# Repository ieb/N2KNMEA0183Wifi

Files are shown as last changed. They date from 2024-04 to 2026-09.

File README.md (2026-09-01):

# N2K / NMEA0183 WiFi + BLE bridge

ESP32-C3 firmware that bridges an NMEA2000 (CAN) bus to WiFi and Bluetooth LE
clients. Parses a working subset of N2K PGNs, emits NMEA0183 and SeaSmart over
TCP/UDP/HTTP streams, serves a local web UI and admin, and publishes a
compact binary boat-state feed over BLE GATT for mobile PWAs.

Also bridges a JBD / JDB BMS over TTL/UART, exposing register data both as
custom PGNs on the N2K bus and as a dedicated BLE battery characteristic.

## Features

* NMEA2000 CAN node — parse + emit, built on top of the NMEA2000 library.
* NMEA0183 generation from N2K PGNs (see `lib/N2KHandler/NMEA0183N2KMessages.h`).
* TCP server on port 10110, UDP broadcast, and long-lived chunked HTTP streams
  (`/api/nmea0183`, `/api/seasmart`) with per-client PGN filtering.
* SeaSmart (PCDIN) passthrough with filter negotiation.
* BLE GATT server (`BoatWatchBLE`) — see `docs/ble-transport.md`:
  * `0xAA00` service — autopilot state, command channel, battery.
  * `0xFF00` service — navigation state (lat/lon, COG/SOG, heading, wind,
    depth, STW, log) and engine state (RPM, temps, volts, pressures, hours,
    status bits).
  * PIN-based auth with per-connection and global brute-force lockouts.
  * Fields revert to "not available" sentinels when their source PGN stops
    arriving (≤15 s for nav and slow-cadence engine fields; 5 s for
    engine-running-only fields), so clients don't see stale values.
* JBD BMS bridge over UART — cell voltages, pack V/I/SoC, temps, FET status,
  errors.
* Engine freeze-frame logging to flash (`lib/freezeframe`).
* Performance calculations (polar VMG, target boat speed, target wind angle,
  leeway — see `lib/performance`).
* Logbook to SPIFFS (`lib/logbook`).
* HTTP admin interface (config upload, FS operations, reboot, status).
* WiFi station or AP mode, mDNS.

## UIs

The UIs live in their own repos and talk to the firmware over HTTP streams
or BLE:

* [N2KBMSFwUi](https://github.com/ieb/N2KBMSFwUi) — read-only SPIFFS-hosted UI
  for mobile browsers.
* [N2KUi](https://github.com/ieb/N2KUi) — installable PWA with admin.
* [N2KLifePo4](https://github.com/ieb/N2KLifePo4) — installable PWA for the
  LiFePO4 BMS (BLE).
* [NMEA2000_Booklet](https://github.com/ieb/NMEA2000_Booklet) — Kindle 4
  booklet for use on deck in sunlight.

## Hardware

Current target is an ESP32-C3 on a custom PCB (see `pcb/`). Brownout
threshold is lowered from the 3.1 V default to 2.8 V to ride out BLE radio
bring-up transients. CAN transceiver, isolated UART to the BMS, LED, and
connectors are documented in the schematic.

<div>
ESP32-C3 board
</div>

## HTTP API

All paths marked "admin only" require HTTP basic auth against credentials in
`config.txt`.

| Method | Path | Purpose |
| --- | ---- | --- |
| GET  | `/**` | Static file from SPIFFS (UI bundle). |
| GET  | `/api/store` | Current store snapshot, CSV. |
| GET  | `/api/devices` | Devices seen on the N2K bus, text. |
| GET  | `/api/nmea0183` | Chunked NMEA0183 stream. |
| GET  | `/api/seasmart` | Chunked SeaSmart stream; `?pgns=...` filters. |
| GET  | `/api/status.json` | Filesystem + heap status. *admin* |
| GET  | `/api/fs.json` | Filesystem listing. *admin* |
| POST | `/api/fs.json` | `op=delete` or `op=upload` (multipart). *admin* |
| GET  | `/config.txt` | Current configuration file. *admin* |
| POST | `/api/reboot.json` | Reboot. *admin* |

Simulators for the HTTP/TCP/BMS side live under `simulator/`.

## TCP / UDP (port 10110)

Emits NMEA0183 sentences by default. A client can switch its session to
SeaSmart by sending a PGN filter request — once switched, the stream stays
in SeaSmart mode for that client. Some noisy PGNs (e.g. Raymarine pilot
updates) are filtered by default to protect bandwidth.

    $PCDCM,1,7,127489,127505,127488,128259,129026,130312,128267*77

UDP is used for broadcast to LAN clients. Note that ChromeOS blocks UDP
broadcast to Android apps running in containers, so the TCP and HTTP stream
paths exist as a workaround.

## BLE

See `docs/ble-transport.md` for the binary frame layouts, magic bytes,
scaling factors, and notification cadence. Characteristics notify at ≤2 Hz
when data changes, and fall back to a 1 Hz keep-alive carrying the latest
values (or NA sentinels if the source PGN has gone stale).

Authentication is a 4-digit PIN (`ble.pin` in `config.txt`). Brute force is
bounded by a per-connection lockout (30 s after 5 failures, disconnect after
10) and a global lockout (5 min after 20 cumulative failures across all
connections). Unauthenticated clients are disconnected after 30 s.

## SeaSmart format reference

SeaSmart/PCDIN sentences published on the NMEA0183 streams:

    $PCDIN,01F119,00000000,0F,2AAF00D1067414FF*59
                                               ^^ checksum
                              ^^^^^^^^^^^^^^^^ data (whole message)
                           ^^ source
                  ^^^^^^^^ hex time
           ^^^^^^ PGN
    ^^^^^^ NMEA0183 id

Hex time decoded as `((parseInt(value,32)/1024)+1262304000)*1000` giving ms
since 1970. Reference: [SeaSmart protocol PDF](http://www.seasmart.net/pdf/SeaSmart_HTTP_Protocol_RevG_043012.pdf).

## Usage

On boot the firmware reads `data/config.txt` from SPIFFS and either joins
the configured WiFi network (station mode) or starts its own AP. Find the
resulting IP, then:

* `http://<ip>/`          — data / status view.
* `http://<ip>/admin.html` — admin view (upload config, reboot).

A serial monitor on the ESP32 gives lower-level diagnostics; press `h<CR>`
for a help screen. The running git SHA is printed with `h`.

## Developing

Project uses PlatformIO. Default environment is `esp32-c3`.

    pio run                                  # build firmware
    pio run -t upload                        # flash firmware
    pio run --target buildfs -e esp32-c3     # build SPIFFS image
    pio run --target uploadfs -e esp32-c3    # flash SPIFFS image
    pio device monitor                       # serial console

The SPIFFS image is populated from `data/`. To repopulate it from the
current UI source, clone the relevant UI repo (for the read-only UI that's
[N2KBMSFwUi](https://github.com/ieb/N2KBMSFwUi)) and run its build script.
Simulators under `simulator/` are Node-based and useful for exercising the
HTTP/TCP/BMS paths without hardware.

## Known limitations / history

* WebSockets were removed — the ESP async WebSocket library crashes when
  more than one client connects and the upstream bug is unfixed. Chunked
  HTTP streams replaced them and are stable under load.
* Earlier PCB revisions carried a BME280, ADS1115, TFT display, touch
  sensors, and an OLED. These are all archived — sensing moved to external
  CAN-based sensors (see CanPressure) and display moved to apps. The
  archived code lives under `lib/archive/`.
* An earlier instability was traced to blocking TCP writes hanging the main
  loop; fixed by moving to an async TCP server. CAN bus loaded to 100 % is
  handled without drops.

## Layout

    src/                 firmware entry point
    lib/
      N2KHandler/        PGN parsing, NMEA0183 emitters, freeze-frame hooks
      bluetooth/         BoatWatch BLE server, engine/nav encoders
      network/           HTTP, TCP, UDP, mDNS, wifi bring-up
      jdbbms/            JBD/JDB BMS UART driver
      performance/       polar-based performance calculations
      logbook/           SPIFFS logbook writer
      freezeframe/       engine event freeze-frame recorder
      config/            config.txt loader
    docs/ble-transport.md   BLE GATT + binary framing spec
    simulator/           Node-based HTTP/TCP/BMS simulators
    pcb/                 board design files
    ui/                  scratch / local UI assets (main UIs are in separate repos)

# BUGS/TODO

* [x] Chromebook and Phone continue to show connection instability. Probably fixed with a 500ppm SCA setting.

## Chromebook and Phone continue to show connection instability. 

Could be the shared WiFi/BLE chips in both devices, but could also be the ESP32 having a 500ppm sleep clock accuracy (SCA). Default with NimBLE seems to be 60ppm. I see 520 connection closed reasons in the ESP32 logs, https://github.com/apache/mynewt-nimble/issues/1777 indicates SCA could be the cause.

Testing over 48h is not conclusive since the WiFi environment is not as challenging with weak signals causing the OS interfer with BLE while prioritising Wifi. However, there seem to be fewer disconnects due to 520, and on that basis I am keeping the 500ppm setting for SCA in this commit.

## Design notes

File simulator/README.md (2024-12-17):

# Various simulators

Simulators used to develop the frimware and clients to the firmware.

Simulate JBD BMS on a serial port at 9600 baud so the firmware can experience a BMS serial port.

node bmssim.js 

Simulate the embedded http api server for seasmart and nmea0183 streams

node index.js

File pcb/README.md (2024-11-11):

# PCBs

There are 2 variant, one for an ESP32 WROOM board and one for ESP32-C3 boards. 2 PCBs for the later one using the 18n pin waveshare module and the other using a generic 16 pin module from ebay.

The BMS serial is isolated with a pair of 6N137s as 0v of the BMS will likely not be 0V of the Canbus due to current flowing from the battery pack.  The device is powered from the canbus which is driven through a TJ1050.  The preferred board is one of the ESP32-C3 boards which are more compact and better designed.

# Gcode generation.

For each board, in KiCad
* generate gerbers for front, back and edge.
* generate 1 drill file with all drills.
* Turn of X2 gerber commands as this creates codes that pcb2gcode wont understand.
* decide on where the mirror line will be, default is X=60, which uses a lot of bed space, sometimes best to use a midpoint on X.
* decide where the alignment holes will be, default is +-10 from the mirror, any y10,80. 4 in total.
* run

        ./createGCode.sh <boardname> <mirrorX> <alignOffsetX>  <alignLowerY> <alignUpperY>
        where:
            boardname is the name of the board
            mirrorX is the X of the mirror line, default 60.
            alignOffsetX is the X distance of alignment holes from the mirror line, default = 10
            alignLowerY is the lower Y position default = 10
            alignUpperY is the upper Y position default = 80

* check the output at https://ncviewer.com/

# Milling

NM grbl 0.9 doesnt process M6 or G81 so both are to be disabled during gcode generation.

* mill the fron side,
* drill alignment
* flip and align
* mill backside
* flip and align
* drill from the frontside

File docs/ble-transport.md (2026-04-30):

# BLE Transport Protocol

The firmware exposes two BLE GATT services: the **BoatWatch Service** for autopilot control and battery monitoring, and the **NMEABridge Nav Service** for navigation data. Up to 3 BLE clients may connect simultaneously.

## Connection

1. Scan for service UUID `0000AA00` (BoatWatch) or `0000FF00` (Nav)
2. Connect GATT
3. Request MTU (64 minimum, 512 recommended)
4. Discover services
5. Enable notifications via CCC descriptor write (UUID `00002902`)
6. Auto-reconnect on disconnect after 3 seconds

Byte order is **little-endian** for all multi-byte values throughout both services.

---

## BoatWatch Service (0xAA00)

Intended mostly for use by wearOS Apps.

| UUID | Characteristic | Properties | Direction |
|---|---|---|---|
| `0000AA00-0000-1000-8000-00805f9b34fb` | Service | -- | -- |
| `0000AA01-0000-1000-8000-00805f9b34fb` | Autopilot State | NOTIFY, READ | Firmware -> Client |
| `0000AA02-0000-1000-8000-00805f9b34fb` | Command | WRITE | Client -> Firmware |
| `0000AA03-0000-1000-8000-00805f9b34fb` | Battery State | NOTIFY, READ | Firmware -> Client |

### Authentication

Autopilot state and battery notifications require authentication. After subscribing to notifications, write an auth command to `0xAA02`:

| Offset | Size | Type | Field | Value |
|---|---|---|---|---|
| 0 | 1 | U8 | magic | `0xAA` |
| 1 | 1 | U8 | cmd | `0xF0` (AUTH) |
| 2 | 4 | char[4] | PIN | ASCII digits, e.g. `"0000"` |

The firmware responds with an auth result notification on both `0xAA01` and `0xAA03`:

| Offset | Size | Type | Field | Value |
|---|---|---|---|---|
| 0 | 1 | U8 | magic | `0xAF` |
| 1 | 1 | U8 | result | `0x01` = accepted, `0x00` = denied |

### Autopilot State (0xAA01)

Magic byte: `0xAA`. Payload: 10 bytes. Update rate: every 5 seconds or on change.

| Offset | Size | Type | Field | Scale/Values |
|---|---|---|---|---|
| 0 | 1 | U8 | magic | `0xAA` |
| 1 | 1 | U8 | mode | 0=STANDBY, 1=COMPASS, 2=WIND_AWA, 3=WIND_TWA |
| 2 | 2 | U16 | current_heading | 0.01 deg (0-36000) |
| 4 | 2 | U16 | target_heading | 0.01 deg (0-36000) |
| 6 | 2 | S16 | target_wind | 0.01 deg (-18000 to +18000) |
| 8 | 2 | U16 | reserved | `0x0000` |

### Commands (0xAA02)

Magic byte: `0xAA`. All commands require prior authentication.

**Autopilot Mode commands (2 bytes, no payload):**

| Cmd | Name |
|-----|---|
| `0x01` | STANDBY |
| `0x02` | COMPASS (heading hold) |
| `0x03` | WIND_AWA (apparent wind) |
| `0x04` | WIND_TWA (true wind) |

**Autopilot Set commands (4 bytes, U16 or S16 payload):**

| Cmd | Name | Payload | Unit |
|-----|---|---|---|
| `0x10` | SET_HEADING | U16 | 0.01 deg (0-36000) |
| `0x11` | SET_WIND | S16 | 0.01 deg |

**Autopilot Adjust commands (4 bytes, S16 payload):**

| Cmd | Name | Payload | Unit |
|-----|---|---|---|
| `0x20` | ADJUST_HEADING | S16 | 0.01 deg delta |
| `0x21` | ADJUST_WIND | S16 | 0.01 deg delta |

**Wifi Adjust commands (2 bytes, No payload):**

| Cmd | Name | Payload | Unit |
|-----|---|---|---|
| `0x40` | ENABLE_WIFI | None | NA |
| `0x41` | DISABLE_WIFI | None | NA |

### Battery State (0xAA03)

Magic byte: `0xBB`. Payload: variable (typically 31 bytes for 4 cells, 3 NTC). Update rate: every 5 seconds or on change.

| Offset | Size | Type | Field | Scale |
|---|---|---|---|---|
| 0 | 1 | U8 | magic | `0xBB` |
| 1 | 2 | U16 | pack_voltage | 0.01 V |
| 3 | 2 | S16 | current | 0.01 A |
| 5 | 2 | U16 | remaining_ah | 0.01 Ah |
| 7 | 2 | U16 | full_ah | 0.01 Ah |
| 9 | 1 | U8 | soc | 1% (0-100) |
| 10 | 2 | U16 | cycles | 1 |
| 12 | 2 | U16 | errors | bitmap (16 protection flags) |
| 14 | 1 | U8 | fet_status | bit0=charge, bit1=discharge |
| 15 | 1 | U8 | n_cells | count |
| 16 | 2*N | U16[] | cell_voltages | 0.001 V each |
| 16+2N | 1 | U8 | n_ntc | count |
| 17+2N | 2*M | U16[] | ntc_temps | 0.1 K (convert: val*0.1 - 273.15 = C) |

---

## NMEABridge Nav Service (0xFF00)

| UUID | Characteristic | Properties | Direction |
|---|---|---|---|
| `0000FF00-0000-1000-8000-00805f9b34fb` | Service | -- | -- |
| `0000FF01-0000-1000-8000-00805f9b34fb` | Navigation State | NOTIFY, READ | Firmware -> Client |
| `0000FF02-0000-1000-8000-00805f9b34fb` | Engine State | NOTIFY, READ | Firmware -> Client |
| `0000FF03-0000-1000-8000-00805f9b34fb` | System | Write |  Client -> Firmware |

Authentication required. Only Authenticated clients receive navigation and engine data.

### Navigation State (0xFF01)

Magic byte: `0xCC`. Payload: 29 bytes. Update rate: 1 Hz.

| Offset | Size | Type | Field | Scale | Range |
|---|---|---|---|---|---|
| 0 | 1 | U8 | magic | `0xCC` | identifier |
| 1 | 4 | S32 | latitude | 1e-7 deg | +/-90 deg |
| 5 | 4 | S32 | longitude | 1e-7 deg | +/-180 deg |
| 9 | 2 | U16 | cog | 0.0001 rad | 0-6.2832 |
| 11 | 2 | U16 | sog | 0.01 m/s | 0-655.34 |
| 13 | 2 | S16 | variation | 0.0001 rad | +/-3.1416 |
| 15 | 2 | U16 | heading | 0.0001 rad | 0-6.2832 |
| 17 | 2 | U16 | depth | 0.01 m | 0-655.34 |
| 19 | 2 | U16 | awa | 0.0001 rad | 0-6.2832 |
| 21 | 2 | U16 | aws | 0.01 m/s | 0-655.34 |
| 23 | 2 | U16 | stw | 0.01 m/s | 0-655.34 |
| 25 | 4 | U32 | log | 1 m | 0-4,294,967,294 |

**Data Not Available sentinels (NMEA 2000 convention):**

| Type | Sentinel |
|---|---|
| U16 | `0xFFFF` |
| S16 | `0x7FFF` |
| U32 | `0xFFFFFFFF` |
| S32 | `0x7FFFFFFF` |

### Example payload

```
hex: CC 60 13 D8 1D 40 6A 56 FA 5C 3D 01 01 57 00 5C 3D E2 04 AE 1E 20 03 F0 00 98 3A 00 00
```

Decodes to: 50.0700 N, 009.5000 W, COG 90.0 deg, SOG 2.57 m/s, VAR 0.5 deg E, HDG 90.0 deg, DEPTH 12.50 m, AWA 45.0 deg, AWS 8.00 m/s, STW 2.40 m/s, LOG 15000 m

### Engine State (0xFF02)

Magic byte: `0xDD`. Payload: 27 bytes. Update rate: 1 Hz max, notify on change. Single engine (instance 0).

The engine is not always running. When 127488 / 127489 stop arriving, the firmware applies a 5 s staleness timeout and reports the "not available" sentinel for RPM, coolant, alternator V/T, oil pressure and status bits. Fuel level, engine-room temperature and engine battery voltage continue to update regardless.

| Offset | Size | Type | Field | Scale | Range |
|---|---|---|---|---|---|
| 0  | 1 | U8  | magic | `0xDD` | identifier |
| 1  | 2 | U16 | rpm | 0.25 rpm/bit | 0-16383.75 rpm |
| 3  | 4 | U32 | engine_hours | 1 s/bit | cumulative, EEPROM-backed |
| 7  | 2 | U16 | coolant_temp | 0.01 K | convert: `val*0.01 - 273.15` = degC |
| 9  | 2 | U16 | alternator_temp | 0.01 K | convert: `val*0.01 - 273.15` = degC (see Non-Standard Mappings) |
| 11 | 2 | U16 | alternator_volts | 0.01 V | 0-655.34 V |
| 13 | 2 | U16 | oil_pressure | 100 Pa/bit | 0-6553400 Pa (1 hPa per count) |
| 15 | 2 | U16 | exhaust_temp | 0.01 K | PGN 130312/130316 source 14 |
| 17 | 2 | U16 | engine_room_temp | 0.01 K | PGN 130312/130316 source 3 |
| 19 | 2 | U16 | engine_batt_volts  | 0.01 V | cranking battery, PGN 127508 instance 0 |
| 21 | 2 | U16 | fuel_level | 0.004 %/bit  | 0-25000 = 0-100 % |
| 23 | 2 | U16 | status1 | bitmap | see Status Bits |
| 25 | 2 | U16 | status2 | bitmap | see Status Bits |

**Data Not Available sentinels** (same convention as Navigation State): `U16 = 0xFFFF`, `U32 = 0xFFFFFFFF`.

#### Status Bits

`status1` - PGN 127489 Discrete Status 1:

| Bit | Mask | Name | Trigger |
|-----|---|---|---|
| 0  | `0x0001` | CHECK_ENGINE | latched on any fault |
| 1  | `0x0002` | OVER_TEMPERATURE | coolant > 97 degC for 15 s |
| 2  | `0x0004` | LOW_OIL_PRESSURE | oil < ~68.9 kPa for 5 s (only while > 800 rpm) |
| 5  | `0x0020` | LOW_SYSTEM_VOLTAGE | battery < 11.8 V for 5 s |
| 7  | `0x0080` | WATER_FLOW | exhaust > 80 degC |
| 9  | `0x0200` | CHARGE_INDICATOR | alternator < 12.2 V for 5 s |
| 15 | `0x8000` | EMERGENCY_STOP | latched |

`status2` - PGN 127489 Discrete Status 2:

| Bit | Mask | Name | Trigger |
|-----|---|---|---|
| 3 | `0x0008` | MAINTENANCE_NEEDED | scheduled service due |
| 4 | `0x0010` | ENGINE_COMM_ERROR | sensor failure detected |
| 7 | `0x0080` | ENGINE_SHUTTING_DOWN  | RPM dropped below 500 with alarms latched |

All other bits are reserved and should be masked off by clients.

#### Non-Standard Mappings

The upstream N2KEngine firmware (https://github.com/ieb/N2KEngine) remaps several PGN fields to carry measurements that have no standard slot. Consumers that read the source PGNs directly must be aware of these remappings; this characteristic presents the decoded values in their logical positions.

1. **`alternator_temp` originates from the PGN 127489 engine-oil-temperature field.** The engine has no oil temperature sensor. The firmware comment ("alternator temperature as engineOil temperature, more important with LiFePO4") documents the substitution. True oil temperature is never emitted.
2. **PGN 127508 instance 2 is a synthetic "battery"** whose Battery Voltage = alternator output and Battery Temperature = alternator NTC. It is not a real battery. `alternator_volts` and `alternator_temp` in this characteristic are sourced from PGN 127489, not from instance 2; clients should ignore PGN 127508 instance 2 entirely.
3. **N2KEngine may emit the engine temperature triplet on legacy PGN 130312 or on PGN 130316.** The bridge accepts either PGN for source 14 (exhaust) and source 3 (engine room) and normalizes them into this characteristic.
4. **Firmware-proprietary temperature sources 30 and 31+** are not surfaced here. Source 30 duplicates the alternator NTC, while sources 31+N expose OneWire DS18B20 probes of variable count.

Exhaust temperature (source 14) and engine-room temperature (source 3) are standard NMEA 2000 temperature sources.

#### Fields deliberately excluded

The N2KEngine firmware never populates fuel rate, coolant pressure, fuel pressure, boost pressure, engine load, engine torque or tilt/trim, so they are omitted here.

### Example payload

```
hex: DD 20 1C F0 D3 1D 00 E7 8B FF 87 8C 05 AC 0D B3 E7 4B 73 EC 04 3E 49 00 00 00 00
```

Decodes to: RPM 1800, engine_hours 543 h (1,954,800 s), coolant 85.0 degC, alternator 75.0 degC / 14.20 V, oil pressure 350 kPa, exhaust 320.0 degC, engine room 22.0 degC, engine battery 12.60 V, fuel 75.0 %, no alarms.

---

#### Data Sources

| Field | NMEA 2000 PGN | Notes |
|---|---|---|
| Latitude, Longitude | 129025, 129029 | GNSS position |
| COG, SOG | 129026 | Course/speed over ground |
| Variation | 127258, 127250 | Magnetic variation |
| Heading | 127250 | Magnetic heading |
| Depth | 128267 | Depth below transducer |
| AWA, AWS | 130306 | Apparent wind |
| STW | 128259 | Speed through water |
| Log | 128275 | Cumulative distance |
| Autopilot | 65379, 65359, 65360, 65345 | Raymarine proprietary |
| Battery | JDB BMS via serial | Registers 03/04 |
| Engine RPM | 127488 | Rapid engine, 500 ms |
| Engine hours, coolant, alternator V, alternator T, oil pressure, status | 127489 | Dynamic engine, 1 s; alternator T carried in oil-temp field (remap) |
| Exhaust temp | 130312/130316 src 14 | Legacy/extended temperature |
| Engine room temp | 130312/130316 src 3  | Legacy/extended temperature |
| Engine battery volts | 127508 instance 0 | Cranking battery |
| Fuel level | 127505 instance 0 | Diesel, 60 L capacity |

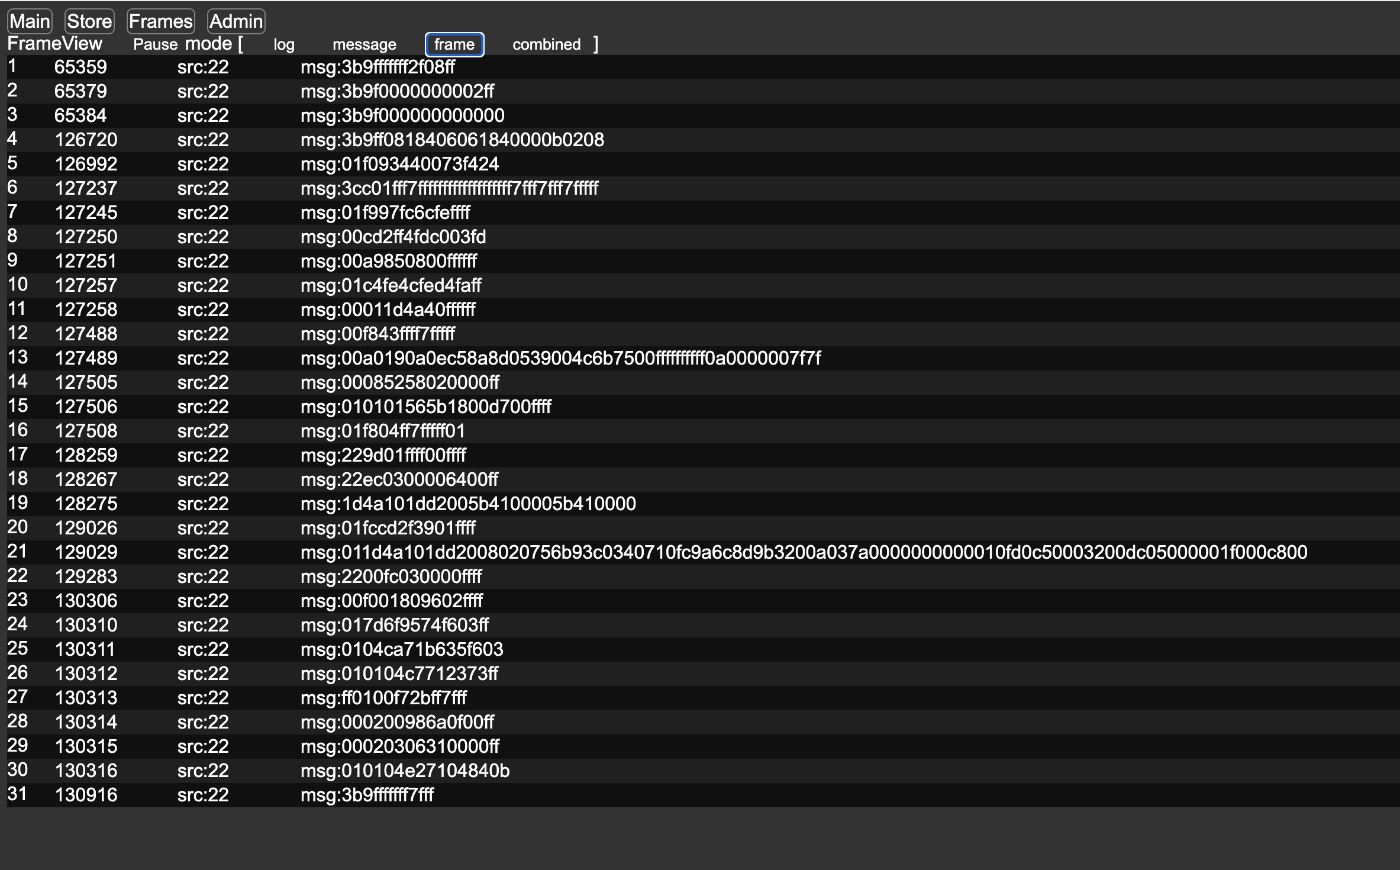
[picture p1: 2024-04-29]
screenshots/frameview.png

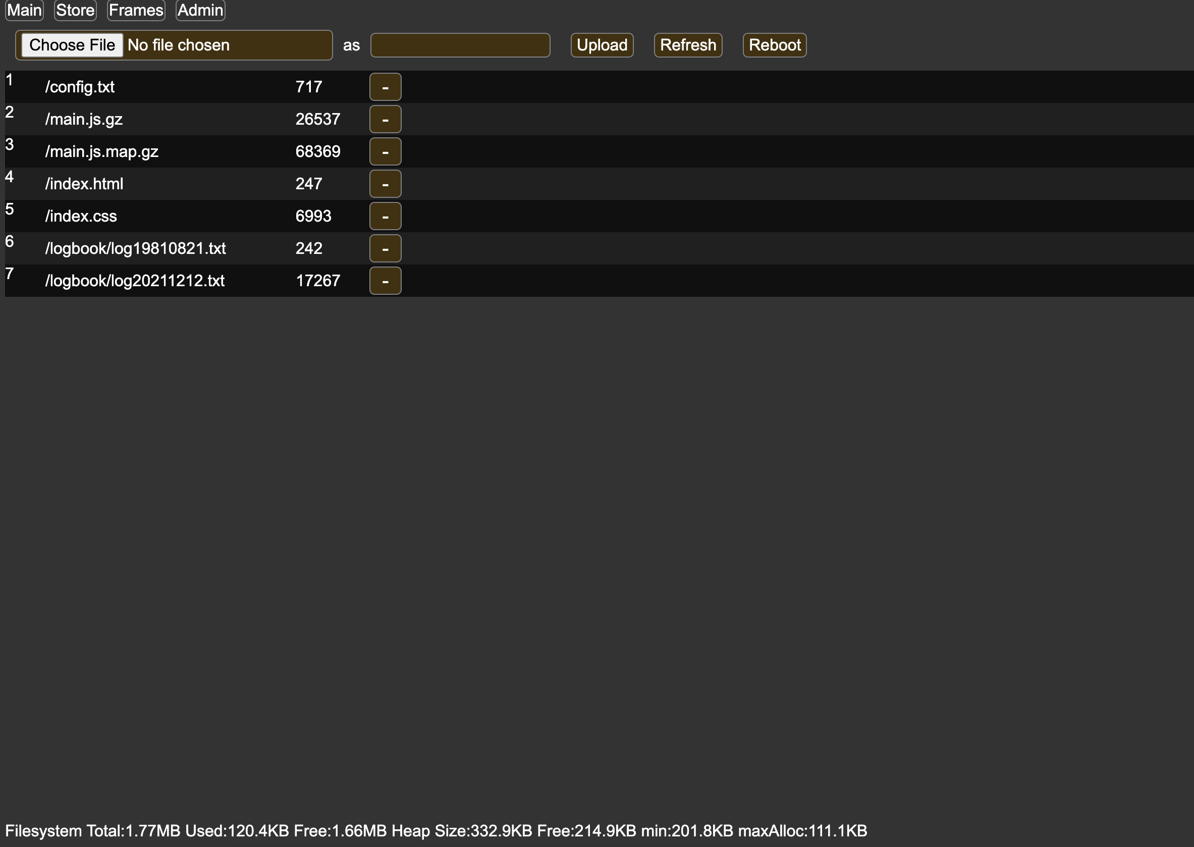
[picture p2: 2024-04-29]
screenshots/admin.png

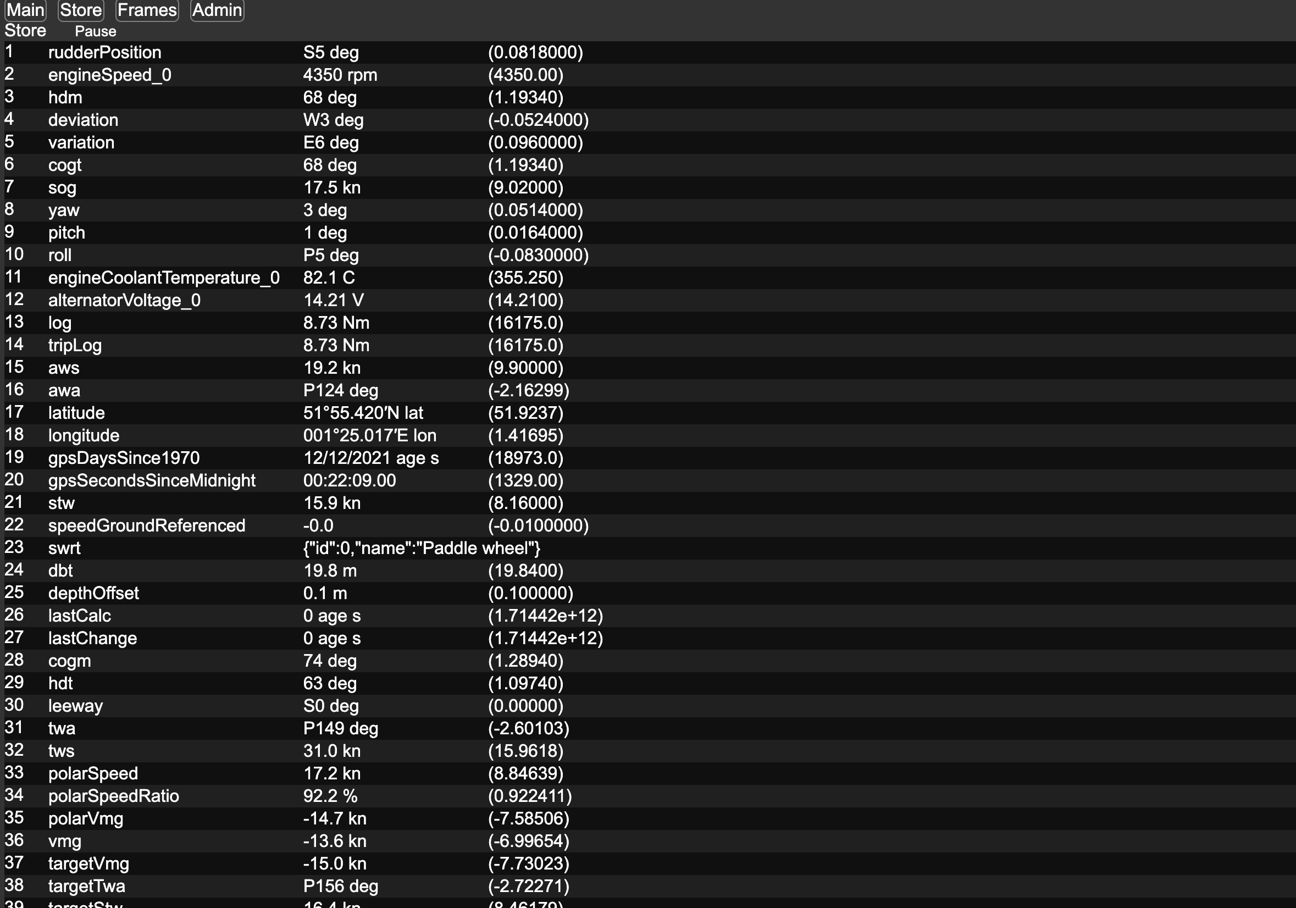
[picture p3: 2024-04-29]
screenshots/decodedstore.png

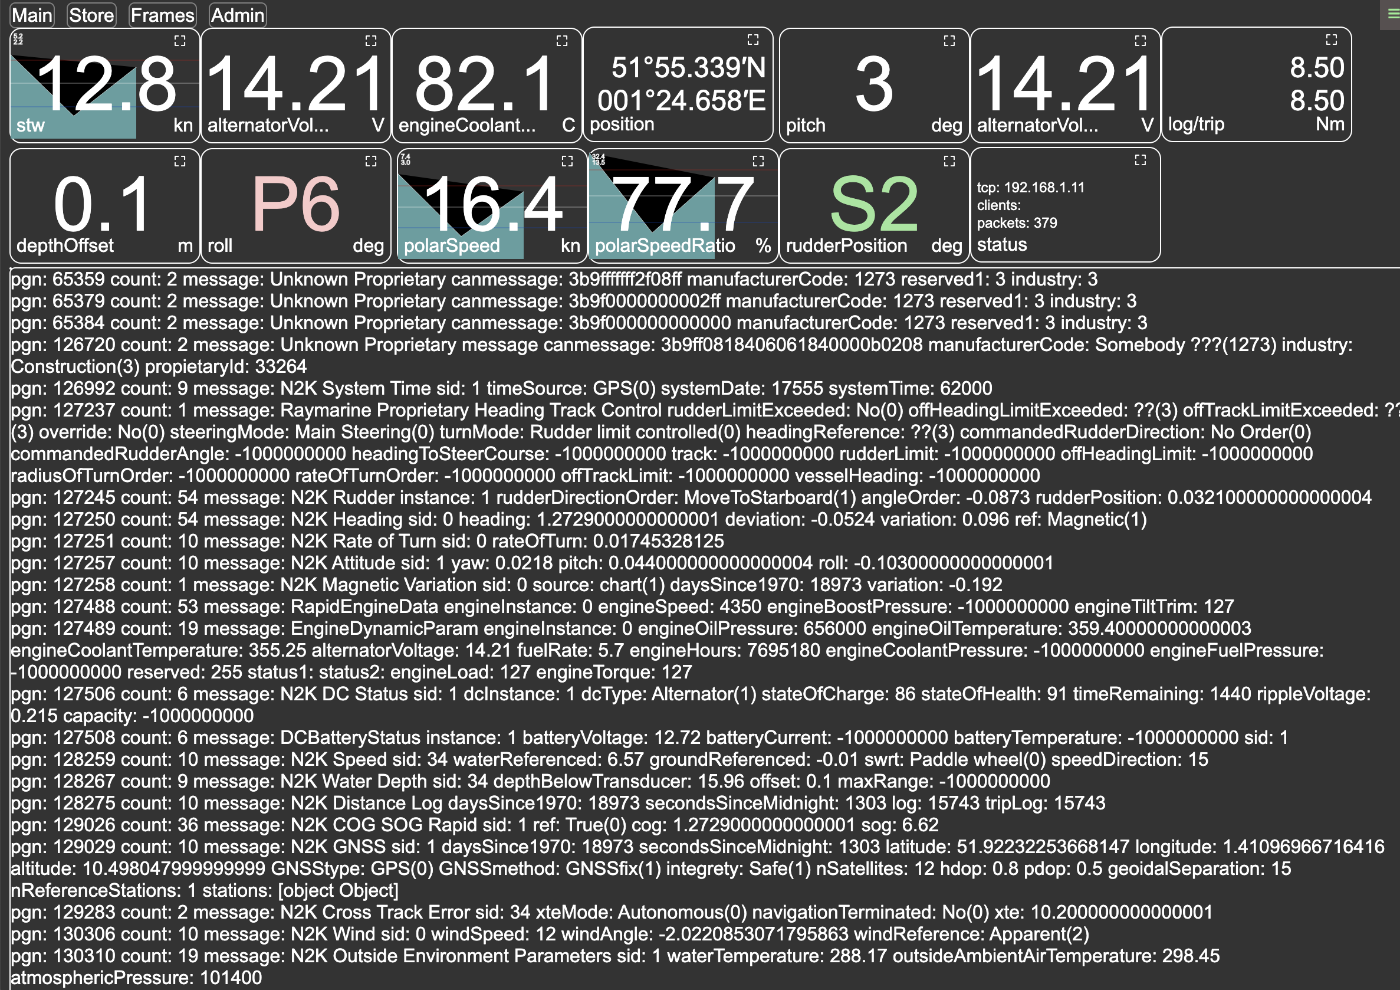
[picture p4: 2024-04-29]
screenshots/instruments.png

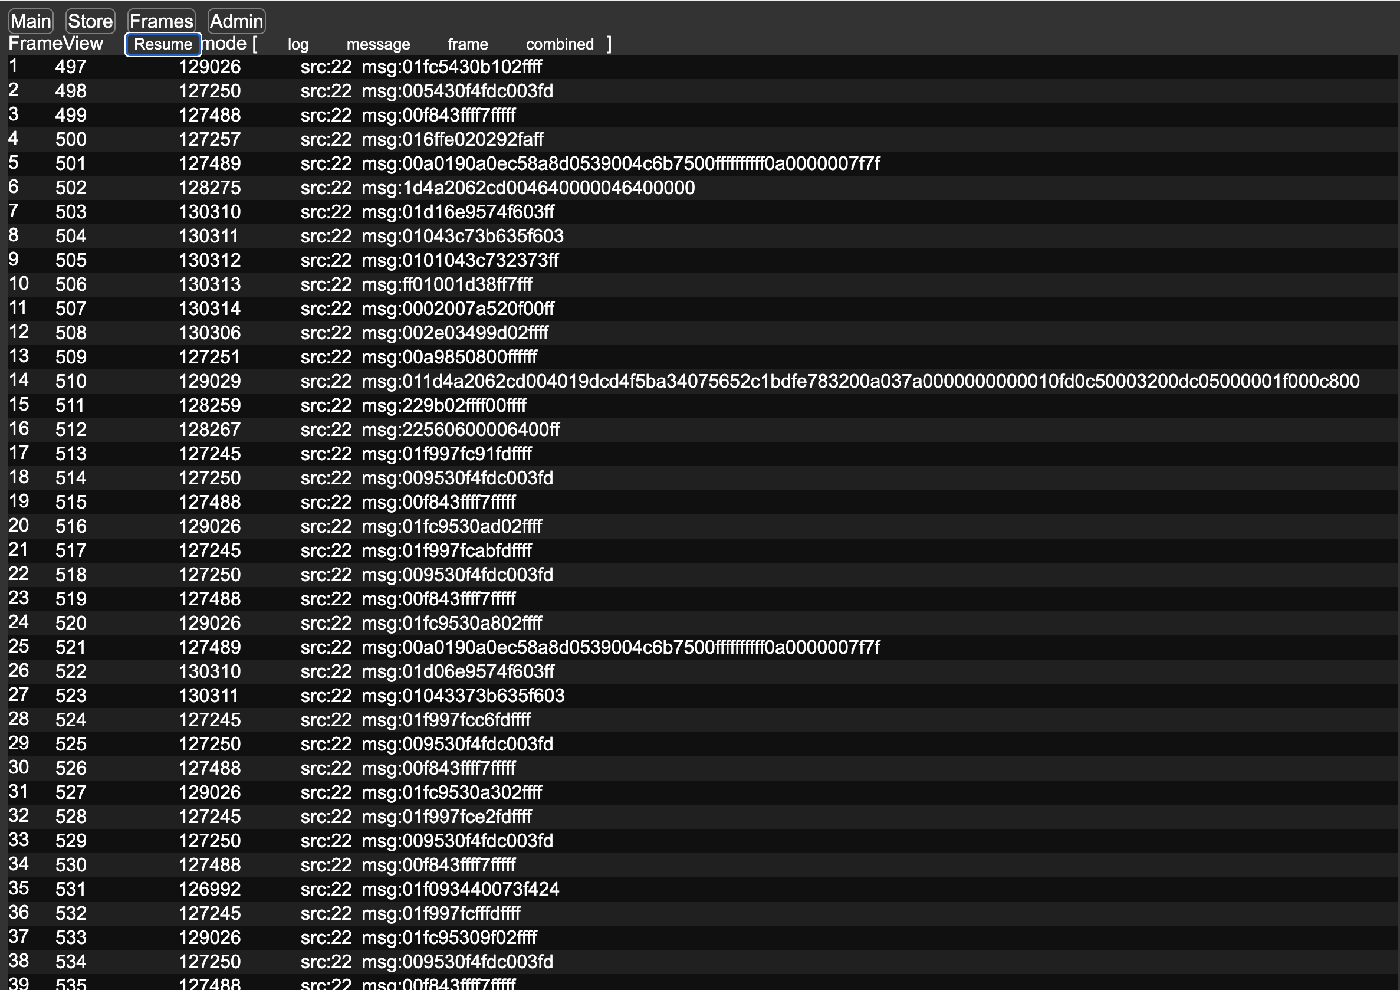
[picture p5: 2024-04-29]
screenshots/streaminglog.png

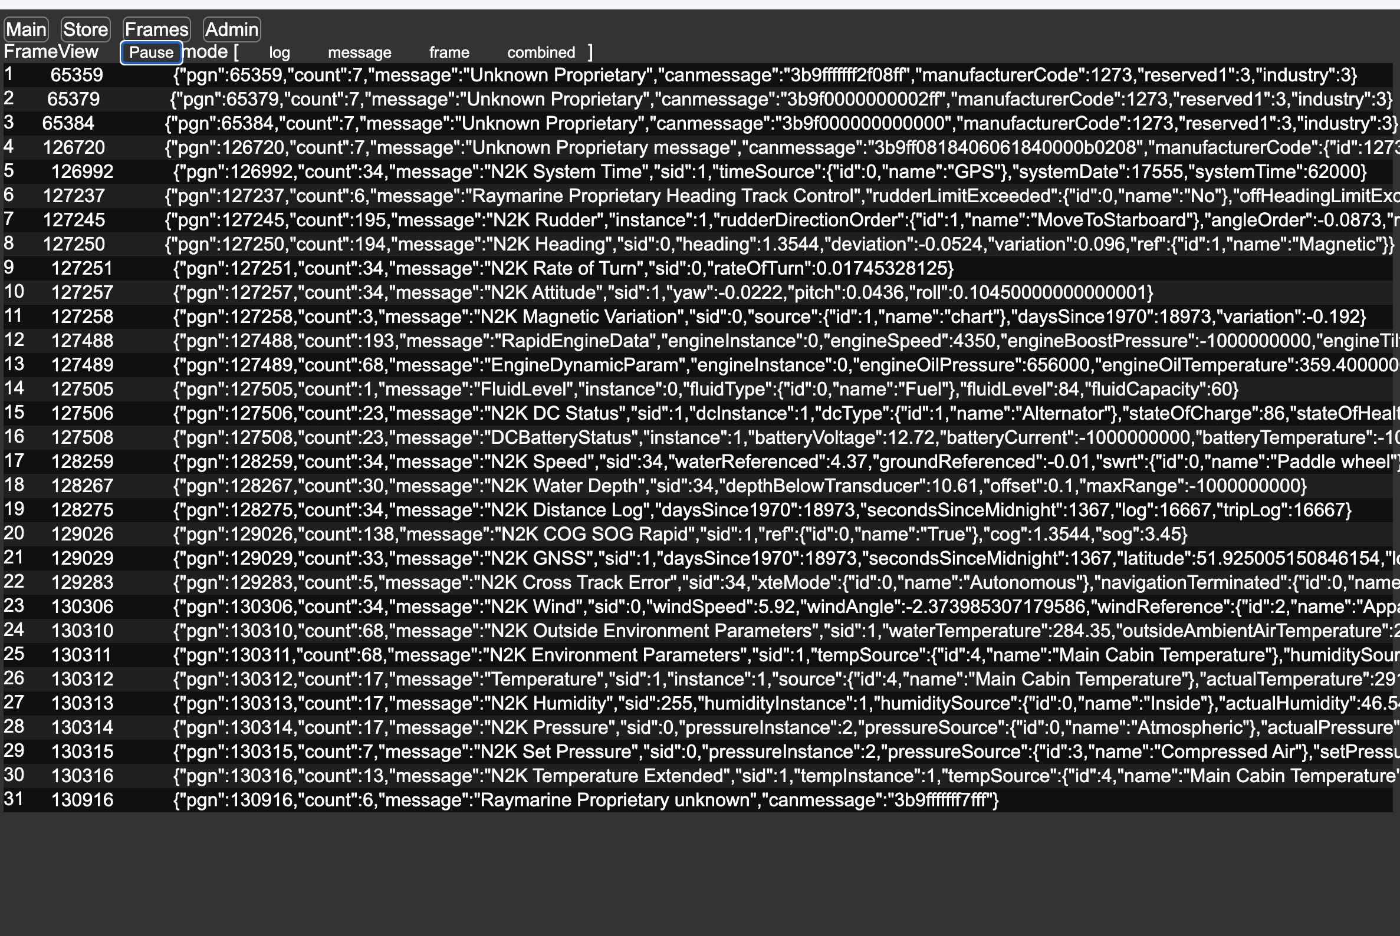
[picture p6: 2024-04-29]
screenshots/messageview.png

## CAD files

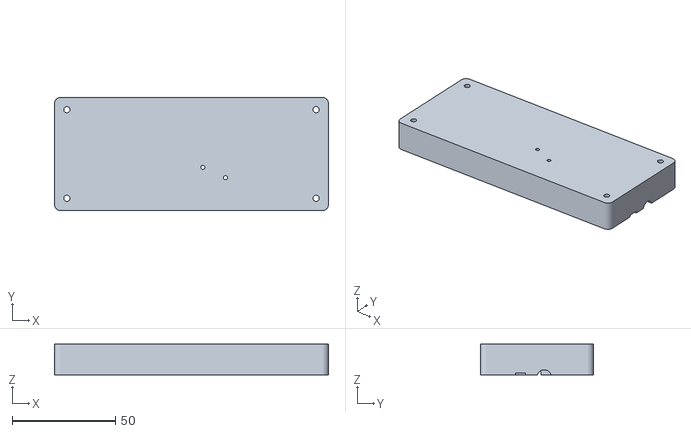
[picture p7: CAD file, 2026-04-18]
pcb/lid.stl
133.0 x 55.0 x 15.0

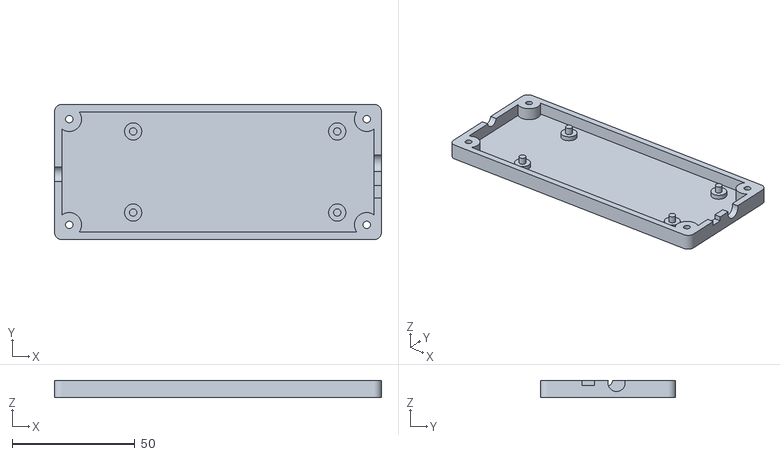
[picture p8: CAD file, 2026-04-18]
pcb/case.stl
133.0 x 55.0 x 7.00

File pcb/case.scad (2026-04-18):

$fn=100;




module board() {
    translate([25,3,0])
    difference() {
        union() {
           translate([0,0,0])
            cube([95,41,2]);
           // connectors
            color("blue") {
                // ESP323C
                translate([44,2,0])
                cube([18,22,6]);
                // Supply
                translate([12,33,0])
                cube([17,6,12]);

                // bms connector
                translate([29,6,2])
                cube([6,12,12]);
                
                // can cable
                translate([95,24,0])
                rotate([0,90,0]) {
                cylinder(d=7, h=50);
                }
                // serial cable
                translate([95,10,0])
                cube([50,5,3]);
            }
            // es32c3 leds
            color("red") {
                translate([58,9,0])
                cylinder(h=9,d=2);
                translate([47,14.5,0])
                cylinder(h=9,d=2);
            }          
           // switch 
            translate([-20,13,0]) {
                cube([18,13,7]);
                translate([-8,13/2,7/2])
                rotate([0,90,0])
                    cylinder(h=8,d=6);
            }
 
        };
        // holes
            translate([7,4,-2])
            cylinder(h=10,d=3);
            translate([7,37,-2])
            cylinder(h=10,d=3);
            translate([90,4,-2])
            cylinder(h=10,d=3);
            translate([90,37,-2])
            cylinder(h=10,d=3);
    }
}

module lid(w=133,d=55,h=17,t=3) {
   difference() {
        translate([w/2,d/2-4,10]) 
      difference() {
        union() {
            difference() {
                union() {
                    cube([w-t*2,d,h], center=true);
                    cube([w,d-t*2,h], center=true);
                    translate([w/2-t,d/2-t,0])
                    cylinder(r=t,h=h, center=true);
                    translate([-(w/2-t),d/2-t,0])
                    cylinder(r=t,h=h, center=true);
                    translate([-(w/2-t),-(d/2-t),0])
                    cylinder(r=t,h=h, center=true);
                    translate([w/2-t,-(d/2-t),0])
                    cylinder(r=t,h=h, center=true);
                    

                }
                // inside
                translate([0,0,-t*2])
                    cube([w-t*2,d-t*2,h+t*2], center=true);
            }
            
            

            
            // fxings
            translate([w/2-2*t,d/2-2*t,0])
                    cylinder(r=5,h=h, center=true);
            translate([-(w/2-2*t),d/2-2*t,0])
                    cylinder(r=5,h=h, center=true);
            translate([-(w/2-2*t),-(d/2-2*t),0])
                    cylinder(r=5,h=h, center=true);
                    translate([w/2-2*t,-(d/2-2*t),0])
                    cylinder(r=5,h=h, center=true);
        }
        
            translate([w/2-2*t,d/2-2*t,0])
                    cylinder(d=3,h=h+10, center=true);
            translate([-(w/2-2*t),d/2-2*t,0])
                    cylinder(d=3,h=h+10, center=true);
            translate([-(w/2-2*t),-(d/2-2*t),0])
                    cylinder(d=3,h=h+10, center=true);
                    translate([w/2-2*t,-(d/2-2*t),0])
                    cylinder(d=3,h=h+10, center=true);
    }
    



        // led
    translate([25,3,0]) {

        translate([58,9,0])
                cylinder(h=50,d=4);
        translate([47,14,0])
                cylinder(h=50,d=4);
    }
  
        board();

    }

}

module case(w=133,d=55,h=9,t=3) {
   difference() {
   translate([w/2,d/2-4,-2.6]) 
      difference() {
        union() {
            difference() {
                union() {
                    cube([w-t*2,d,h], center=true);
                    cube([w,d-t*2,h], center=true);
                    translate([w/2-t,d/2-t,0])
                    cylinder(r=t,h=h, center=true);
                    translate([-(w/2-t),d/2-t,0])
                    cylinder(r=t,h=h, center=true);
                    translate([-(w/2-t),-(d/2-t),0])
                    cylinder(r=t,h=h, center=true);
                    translate([w/2-t,-(d/2-t),0])
                    cylinder(r=t,h=h, center=true);
                    

                }
                // inside
                translate([0,0,t])
                    cube([w-t*2,d-t*2,h+t], center=true);
            }
            

            // fxings
            translate([w/2-2*t,d/2-2*t,0])
                    cylinder(r=5,h=h, center=true);
            translate([-(w/2-2*t),d/2-2*t,0])
                    cylinder(r=5,h=h, center=true);
            translate([-(w/2-2*t),-(d/2-2*t),0])
                    cylinder(r=5,h=h, center=true);
                    translate([w/2-2*t,-(d/2-2*t),0])
                    cylinder(r=5,h=h, center=true);
        }
        
            translate([w/2-2*t,d/2-2*t,0])
                    cylinder(d=3,h=h+10, center=true);
            translate([-(w/2-2*t),d/2-2*t,0])
                    cylinder(d=3,h=h+10, center=true);
            translate([-(w/2-2*t),-(d/2-2*t),0])
                    cylinder(d=3,h=h+10, center=true);
                    translate([w/2-2*t,-(d/2-2*t),0])
                    cylinder(d=3,h=h+10, center=true);
        }
        board();
        
        
    }
}
module cables() {
    /*
    translate([-90,-15,10])
    rotate([0,90,0])
    cylinder(d=2,h=90);
    
    translate([-90,15,10])
    rotate([0,90,0])
    cylinder(d=4,h=90);
*/
    translate([45,0,4.5])
            cube([20,17,8], center=true);


/*
    translate([-90,0,0])
    rotate([0,90,0])
    cylinder(d=4,h=90);

    color("red")
    translate([0,0,0])
    rotate([0,90,0])
    cylinder(d=7,h=90);
    */
}




/*
difference() {
    union() {
        board();
        color("green") case();
        lid();
    }

   translate([10,0,0])
       cube([100,100,140], center=true);
}
*/




//board();
//color("green") case();
lid();

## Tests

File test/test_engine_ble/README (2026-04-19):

Native test for the Engine State (0xFF02) BLE characteristic encoder.

Build and run:

    cd test/test_engine_ble
    gcc test_engine_ble.c -I../../lib/bluetooth -o run && ./run

The test includes lib/bluetooth/engine_ble_encoder.h directly (it has no
Arduino / NimBLE dependencies) and byte-compares the encoded payload against
the "Example payload" in docs/ble-transport.md.

Cases:
  - golden_example         : 27 bytes match the documented hex exactly.
  - all_sentinels          : every field "not available" encodes as 0xFF fill.
  - partial_availability   : engine off, only fuel+hours live.
  - length                 : encoder returns 27.
  - rpm_boundary           : 0 and 16383.75 (the latter aliases sentinel by design).

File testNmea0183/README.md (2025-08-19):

# test nmea0183 tcp port

	npm install
    nc 192.168.4.1 10110 | ./node_modules/\@signalk/nmea0183-signalk/bin/nmea0183-signalk

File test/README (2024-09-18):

This directory contains tests to be run with 

    gcc <filename> && ./a.out

The tests are self contained to test functions and code rather than test the final codebase as this allows a
much faster cycle time than running on the target MCU, especially if the target MCU is not available.

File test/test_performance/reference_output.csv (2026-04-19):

# seed=42 grid_rows=460 random_rows=1000
iter | awa | aws | stw | roll | hdm | variation | tag | tws | twa | leeway | polarSpeed | polarSpeedRatio | polarVmg | vmg | targetTwa | targetVmg | targetStw | polarVmgRatio | windDirectionTrue | windDirectionMagnetic | oppositeTrackHeadingTrue | oppositeTrackHeadingMagnetic | oppositeTrackTrue | oppositeTrackMagnetic
0 | 0.012720583 | 3.528194666 | 2.500000000 | -1000000000.0 | 1.000000000 | 0.100000001 | P | 1.028889 | 0.043633 | 0.000000 | 0.051444 | 48.596130 | 0.051395 | 2.497621 | 0.750492 | 0.692283 | 0.946578 | 3.607803 | 0.943633 | 1.043633 | 1.594125 | 1.694125 | 1.594125 | 1.694125
1 | -0.012720583 | 3.528194666 | 2.500000000 | -1000000000.0 | 1.000000000 | 0.100000001 | P | 1.028889 | -0.043633 | 0.000000 | 0.051444 | 48.596130 | 0.051395 | 2.497621 | -0.750492 | 0.692283 | 0.946578 | 3.607803 | 0.856367 | 0.956367 | 0.005875 | 0.105875 | 0.005875 | 0.105875
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

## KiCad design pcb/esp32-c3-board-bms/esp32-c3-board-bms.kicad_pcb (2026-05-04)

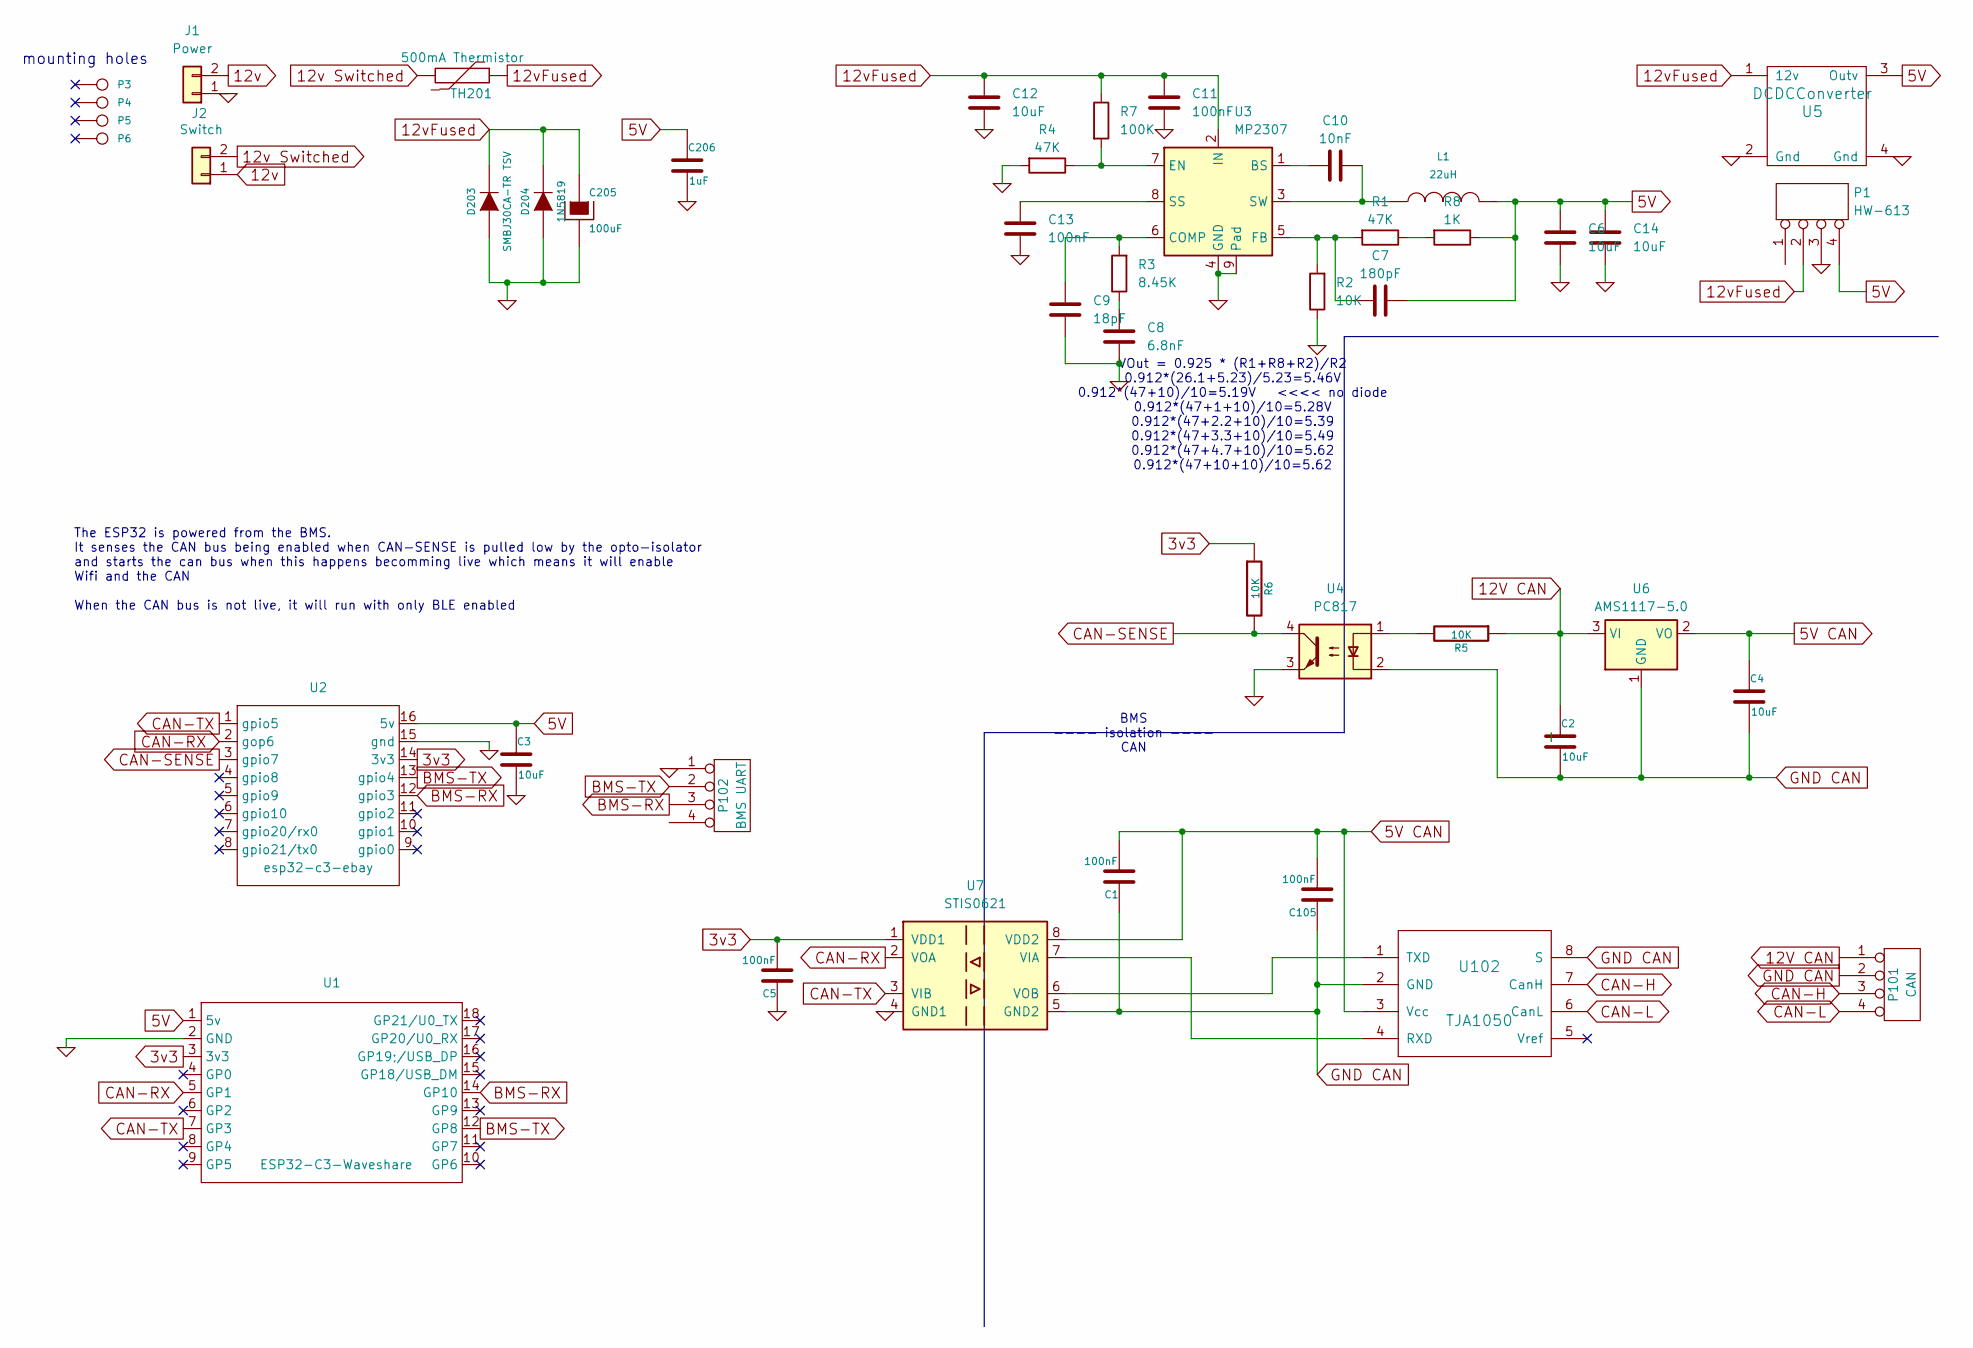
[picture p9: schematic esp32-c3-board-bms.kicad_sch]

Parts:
C1, C5, C11, C13, C105: 100nF; C_0805_2012Metric_Pad1.18x1.45mm_HandSolder
C2, C3, C4, C6, C12, C14: 10uF; C_0805_2012Metric_Pad1.18x1.45mm_HandSolder
C7: 180pF; C_0805_2012Metric_Pad1.18x1.45mm_HandSolder
C8: 6.8nF; C_0805_2012Metric_Pad1.18x1.45mm_HandSolder
C9: 18pF; C_0805_2012Metric_Pad1.18x1.45mm_HandSolder
C10: 10nF; C_0805_2012Metric_Pad1.18x1.45mm_HandSolder
C205: 100uF; C_1206_3216Metric_Pad1.33x1.80mm_HandSolder
C206: 1uF; C_1210_3225Metric_Pad1.33x2.70mm_HandSolder
D203: SMBJ30CA-TR TSV; D_SMB_Handsoldering
D204: 1N5819; D_1206_3216Metric_Pad1.42x1.75mm_HandSolder
J1: Power; JST_XH_B2B-XH-A_1x02_P2.50mm_Vertical
J2: Switch; JST_XH_B2B-XH-A_1x02_P2.50mm_Vertical
L1: 22uH; L_APV_ANR6045
P1: HW-613; PinHeader_1x04_P2.54mm_Vertical
P3, P4, P5, P6: CONN_1; MountingHole_3.5mm
P101: CAN; SolderWire-1.5sqmm_1x04_P6mm_D1.7mm_OD3mm
P102: BMS UART; JST_XH_B4B-XH-A_1x04_P2.50mm_Vertical
R1, R4: 47K; R_0805_2012Metric_Pad1.20x1.40mm_HandSolder
R2, R5, R6: 10K; R_0805_2012Metric_Pad1.20x1.40mm_HandSolder
R3: 8.45K; R_0805_2012Metric_Pad1.20x1.40mm_HandSolder
R7: 100K; R_0805_2012Metric_Pad1.20x1.40mm_HandSolder
R8: 1K; R_0805_2012Metric_Pad1.20x1.40mm_HandSolder
TH201: 500mA Thermistor; R_2010_5025Metric_Pad1.40x2.65mm_HandSolder
U1: ESP32-C3-Waveshare; ESP-C3-Zero-Waveshare
U2: esp32-c3-ebay; ESP-C3-Zero-ebay
U3: MP2307; SOIC-8-1EP_3.9x4.9mm_P1.27mm_EP2.62x3.51mm
U4: PC817; DIP-4_W7.62mm
U5: DCDCConverter; Mini360 DCDCConverter
U6: AMS1117-5.0; SOT-223-3_TabPin2
U7: STIS0621; SOIC-8_3.9x4.9mm_P1.27mm
U102: TJA1050; SOIC-8_3.9x4.9mm_P1.27mm

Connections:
3v3: C5.2, R6.1, U1.3 (3v3), U2.14 (3v3), U7.1 (VDD1)
5V CAN: C1.2, C4.1, C105.2, U6.2 (VO), U7.8 (VDD2), U102.3 (Vcc)
12V CAN: C2.1, P101.1, R5.1, U6.3 (VI)
12v: J1.2, J2.1
12v Switched: J2.2, TH201.2
12vFused: C11.1, C12.1, C205.1, D203.2 (K), D204.2 (K), P1.2, R7.1, TH201.1, U3.2 (IN), U5.1 (12v)
BMS-RX: P102.3, U1.14 (GP10), U2.12 (gpio3)
BMS-TX: P102.2, U1.12 (GP8), U2.13 (gpio4)
CAN-H: P101.3, U102.7 (CanH)
CAN-L: P101.4, U102.6 (CanL)
CAN-RX: U1.5 (GP1), U2.2 (gop6), U7.2 (VOA)
CAN-SENSE: R6.2, U2.3 (gpio7), U4.4
CAN-TX: U1.7 (GP3), U2.1 (gpio5), U7.3 (VIB)
GND: C3.2, C5.1, C6.2, C8.1, C9.1, C11.2, C12.2, C13.2, C14.2, C205.2, C206.2, D203.1 (A), D204.1 (A), J1.1, P1.3, P102.1, R2.1, R4.2, U1.2 (GND), U2.15 (gnd), U3.4 (GND), U3.9 (Pad), U4.3, U5.2 (Gnd), U5.4 (Gnd), U7.4 (GND1)
GND CAN: C1.1, C2.2, C4.2, C105.1, P101.2, U4.2, U6.1 (GND), U7.5 (GND2), U102.2 (GND), U102.8 (S)
unnamed: C8.2, R3.1
unnamed: R1.1, R8.2
unnamed: R5.2, U4.1
unnamed: C10.1, U3.1 (BS)
unnamed: C9.2, R3.2, U3.6 (COMP)
unnamed: R4.1, R7.2, U3.7 (EN)
unnamed: C7.1, R1.2, R2.2, U3.5 (FB)
unnamed: C13.1, U3.8 (SS)
unnamed: C10.2, L1.1, U3.3 (SW)
unnamed: U7.7 (VIA), U102.4 (RXD)
unnamed: U7.6 (VOB), U102.1 (TXD)

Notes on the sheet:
VOut = 0.925 * (R1+R8+R2)/R2 0.912*(26.1+5.23)/5.23=5.46V 0.912*(47+10)/10=5.19V <<<< no diode 0.912*(47+1+10)/10=5.28V 0.912*(47+2.2+10)/10=5.39 0.912*(47+3.3+10)/10=5.49 0.912*(47+4.7+10)/10=5.62 0.912*(47+10+10)/10=5.62
BMS ---- isolation ---- CAN
mounting holes
The ESP32 is powered from the BMS. It senses the CAN bus being enabled when CAN-SENSE is pulled low by the opto-isolator and starts the can bus when this happens becomming live which means it will enable Wifi and the CAN When the CAN bus is not live, it will run with only BLE enabled

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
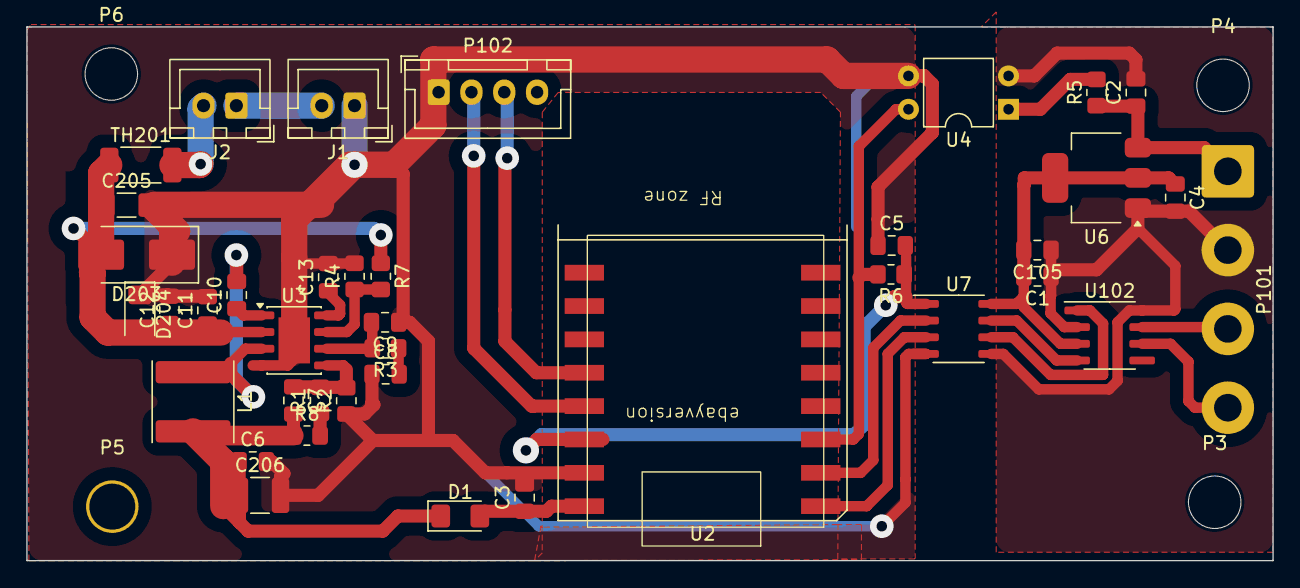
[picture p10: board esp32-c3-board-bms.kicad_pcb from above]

Board: 2 copper layers, 94.9 x 40.6 mm, 43 parts (0 on the bottom side), 28 nets.

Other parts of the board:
D1: 1N5819; D_1206_3216Metric_Pad1.42x1.75mm_HandSolder

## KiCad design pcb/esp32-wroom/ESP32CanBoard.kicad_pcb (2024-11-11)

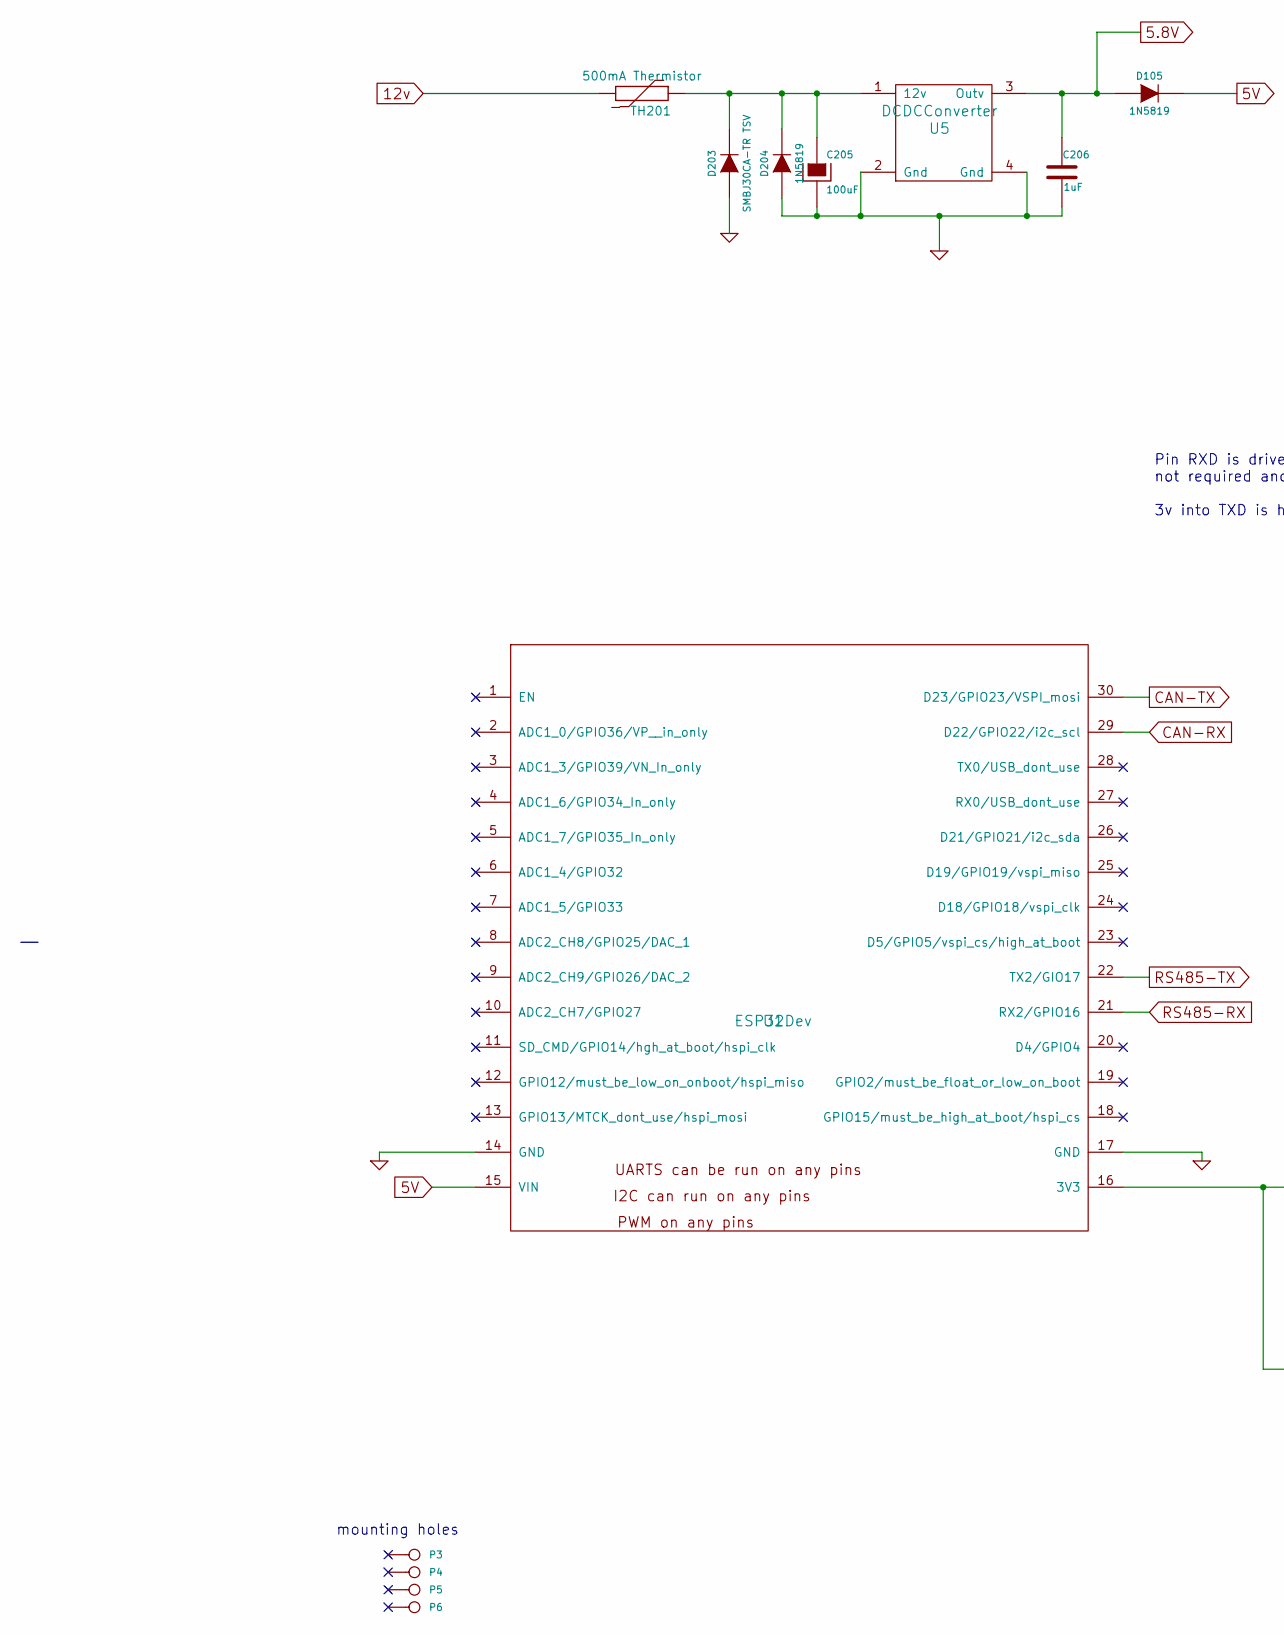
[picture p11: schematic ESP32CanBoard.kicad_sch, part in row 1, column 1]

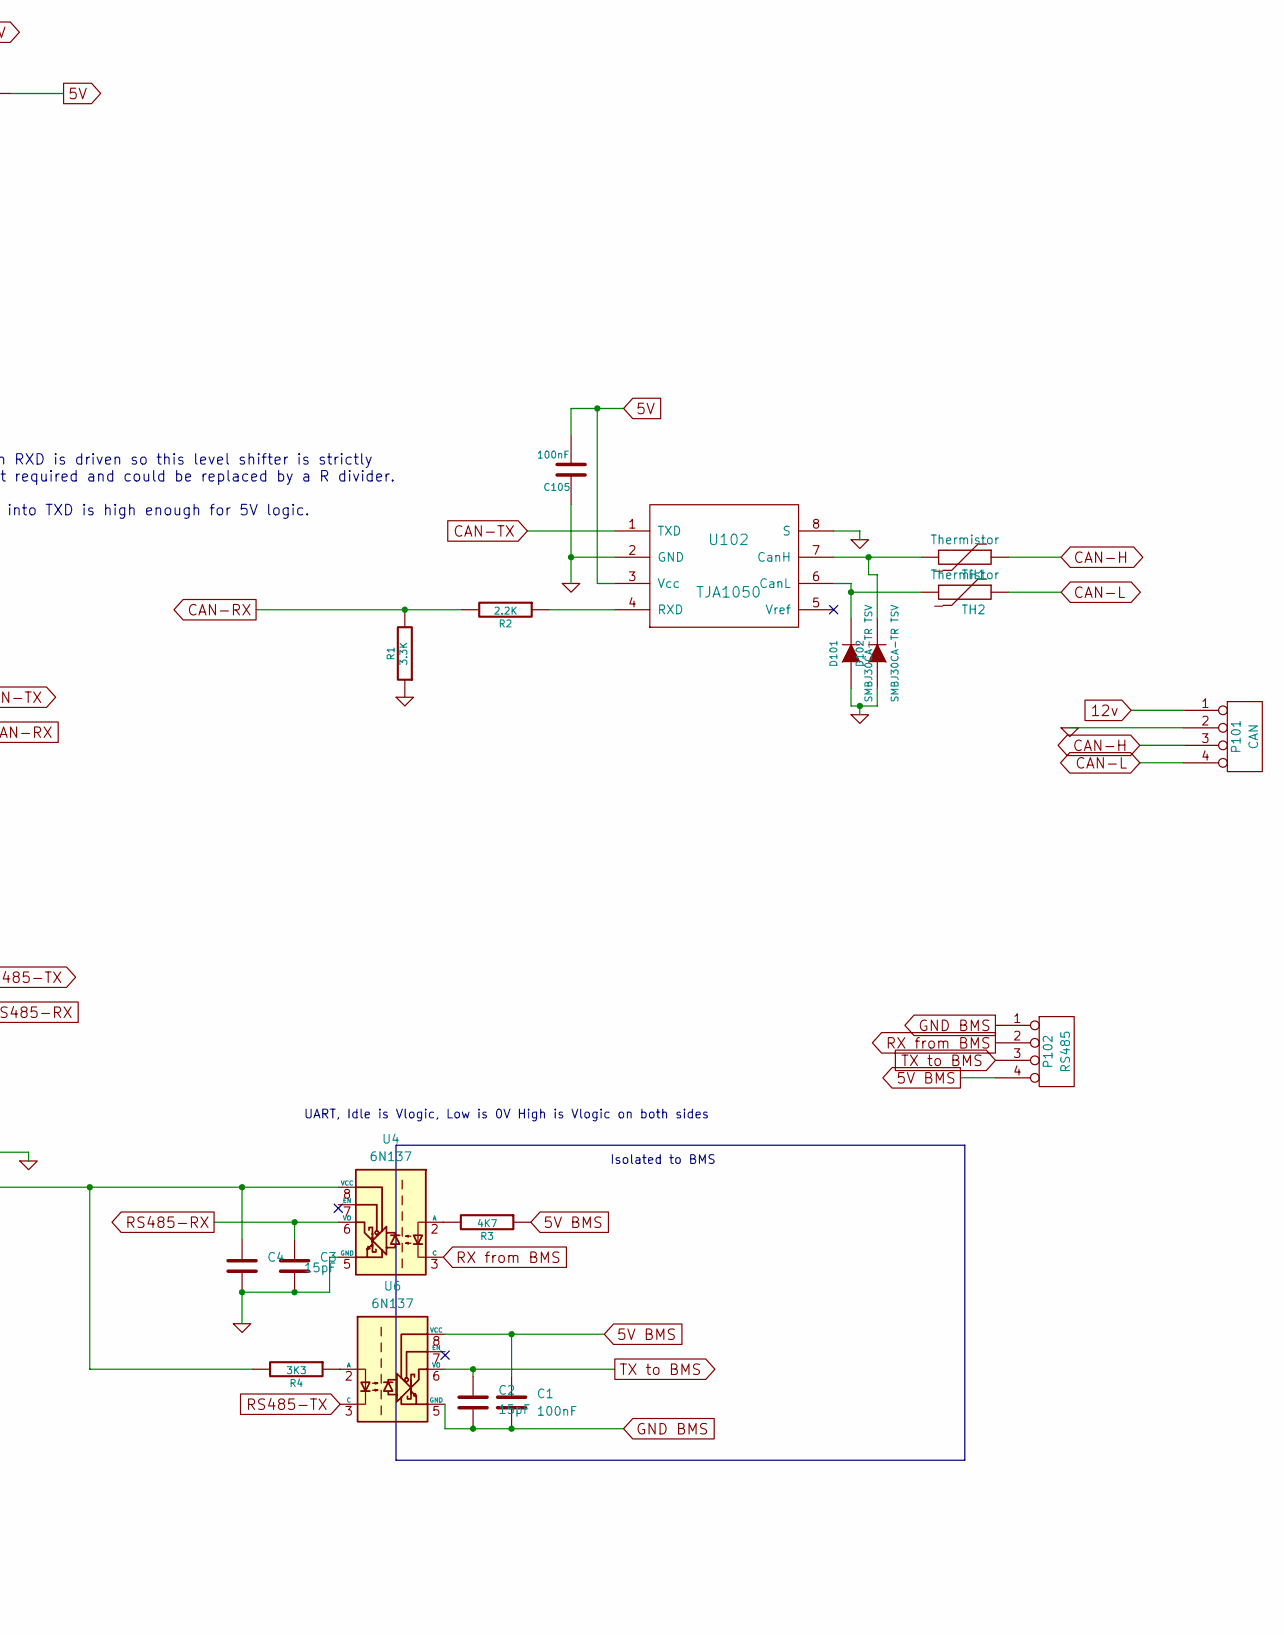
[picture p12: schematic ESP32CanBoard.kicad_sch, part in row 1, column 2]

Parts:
C1, C4, C105: 100nF; C_0805_2012Metric_Pad1.18x1.45mm_HandSolder
C2, C3: 15pF; C_0805_2012Metric_Pad1.18x1.45mm_HandSolder
C205: 100uF; C_1206_3216Metric_Pad1.33x1.80mm_HandSolder
C206: 1uF; C_1210_3225Metric_Pad1.33x2.70mm_HandSolder
D101, D102, D203: SMBJ30CA-TR TSV; DO-214AB
D105, D204: 1N5819; D_1206
P3, P4, P5, P6: CONN_1; 1pin
P101: CAN; bornier4
P102: RS485; JST_XH_S4B-XH-A_1x04_P2.50mm_Horizontal
R1: 3.3K; R_0805_2012Metric_Pad1.20x1.40mm_HandSolder
R2: 2.2K; R_0805_2012Metric_Pad1.20x1.40mm_HandSolder
R3: 4K7; R_0805_2012Metric_Pad1.20x1.40mm_HandSolder
R4: 3K3; R_0805_2012Metric_Pad1.20x1.40mm_HandSolder
TH1, TH2: Thermistor; R_2010_5025Metric_Pad1.40x2.65mm_HandSolder
TH201: 500mA Thermistor; Resistor_Horizontal_RM7mm
U1: ESP32Dev
U4, U6: 6N137; DIP-8_W7.62mm
U5: DCDCConverter; DC-DC-Converter
U102: TJA1050; SOIC-8_3.9x4.9mm_Pitch1.27mm

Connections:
5.8V: C206.1, D105.1 (A), U5.3 (Outv)
5V: C105.2, D105.2 (K), U1.15 (VIN), U102.3 (Vcc)
5V BMS: C1.1, P102.4, R3.1, U6.8 (VCC)
12v: P101.1, TH201.2
CAN-H: P101.3, TH1.1
CAN-L: P101.4, TH2.1
CAN-RX: R1.2, R2.2, U1.29 (D22/GPIO22/i2c_scl)
CAN-TX: U1.30 (D23/GPIO23/VSPI_mosi), U102.1 (TXD)
GND: C3.2, C4.2, C105.1, C205.2, C206.2, D101.1 (A), D102.1 (A), D203.1 (A), D204.1 (A), P101.2, R1.1, U1.14 (GND), U1.17 (GND), U4.5 (GND), U5.2 (Gnd), U5.4 (Gnd), U102.2 (GND), U102.8 (S)
GND BMS: C1.2, C2.2, P102.1, U6.5 (GND)
unnamed: D101.2 (K), TH2.2, U102.6 (CanL)
unnamed: D102.2 (K), TH1.2, U102.7 (CanH)
unnamed: C205.1, D203.2 (K), D204.2 (K), TH201.1, U5.1 (12v)
unnamed: C4.1, R4.2, U1.16 (3V3), U4.8 (VCC)
unnamed: R3.2, U4.2 (A)
unnamed: R4.1, U6.2 (A)
unnamed: R2.1, U102.4 (RXD)
RS485-RX: C3.1, U1.21 (RX2/GPIO16), U4.6 (VO)
RS485-TX: U1.22 (TX2/GIO17), U6.3 (C)
RX from BMS: P102.2, U4.3 (C)
TX to BMS: C2.1, P102.3, U6.6 (VO)

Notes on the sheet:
Pin RXD is driven so this level shifter is strictly not required and could be replaced by a R divider. 3v into TXD is high enough for 5V logic.
mounting holes
Isolated to BMS
UART, Idle is Vlogic, Low is 0V High is Vlogic on both sides

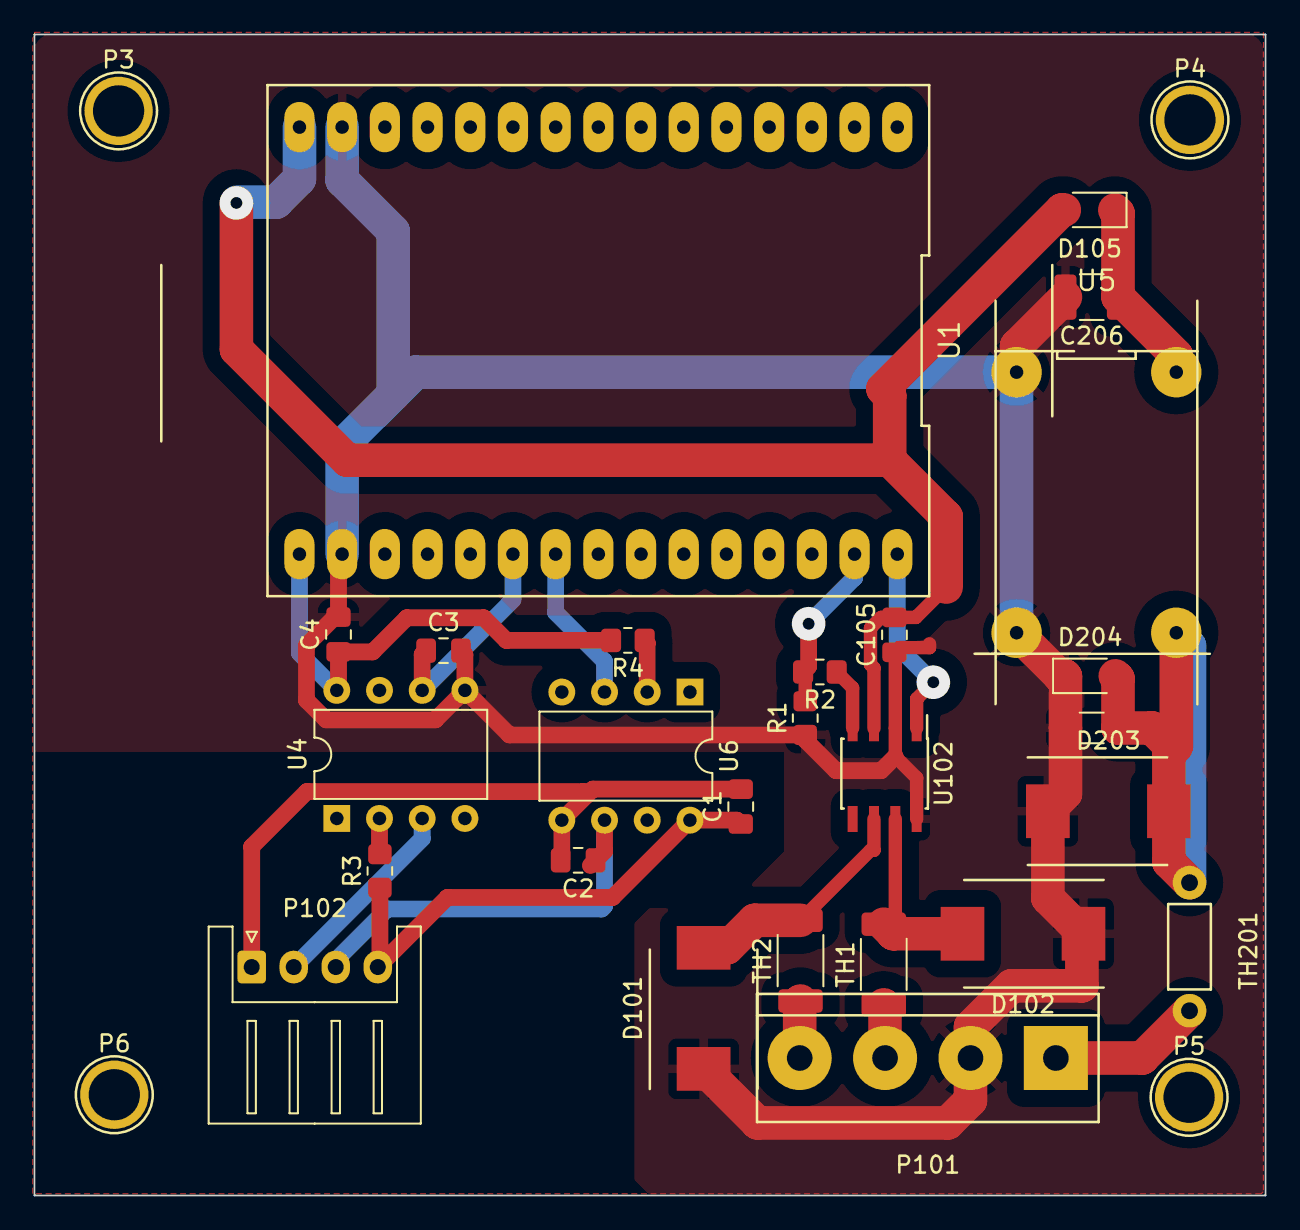
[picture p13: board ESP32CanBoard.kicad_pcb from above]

Board: 2 copper layers, 73.2 x 69.1 mm, 30 parts (0 on the bottom side), 21 nets.

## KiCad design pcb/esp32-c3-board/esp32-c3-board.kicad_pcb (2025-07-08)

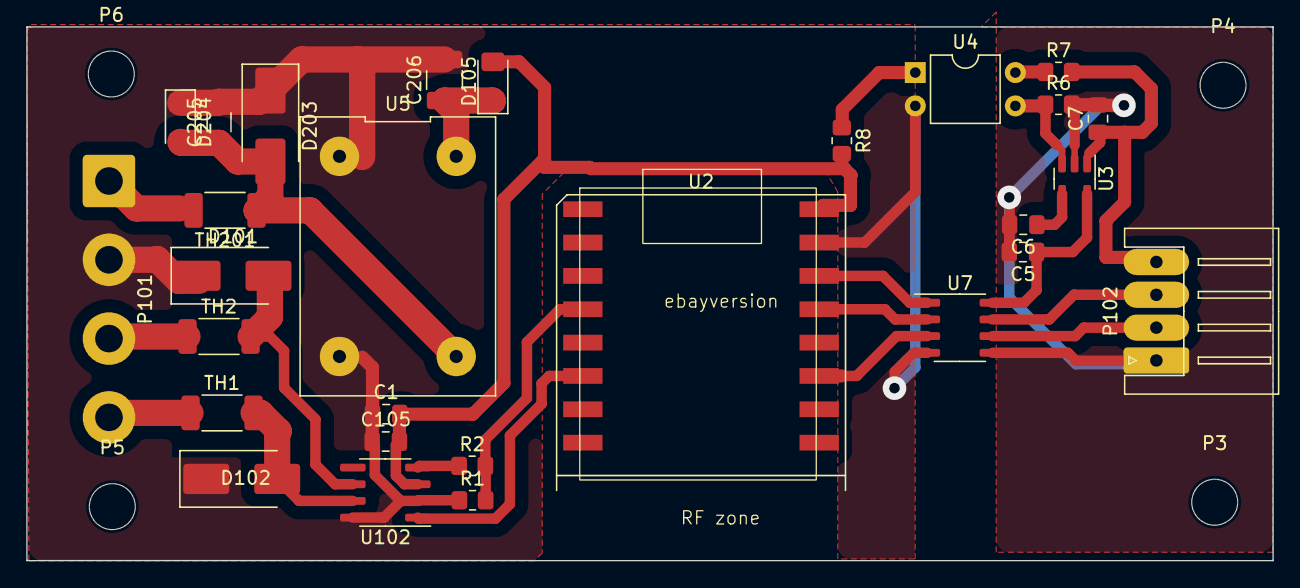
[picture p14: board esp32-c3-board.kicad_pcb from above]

Board: 2 copper layers, 94.9 x 40.6 mm, 32 parts (0 on the bottom side), 24 nets.

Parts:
C1, C5, C7: 10uF; C_0805_2012Metric_Pad1.18x1.45mm_HandSolder
C6: 10nF; C_0805_2012Metric_Pad1.18x1.45mm_HandSolder
C105: 100nF; C_0805_2012Metric_Pad1.18x1.45mm_HandSolder
C205: 100uF; C_1206_3216Metric_Pad1.33x1.80mm_HandSolder
C206: 1uF; C_1210_3225Metric_Pad1.33x2.70mm_HandSolder
D101, D102, D203: SMBJ30CA-TR TSV; D_SMB_Handsoldering
D105, D204: 1N5819; D_1206_3216Metric_Pad1.42x1.75mm_HandSolder
P3, P4, P5, P6: CONN_1; MountingHole_3.5mm
P101: CAN; SolderWire-1.5sqmm_1x04_P6mm_D1.7mm_OD3mm
P102: BMS UART; JST_XH_S4B-XH-A_1x04_P2.50mm_Horizontal
R1: 3.3K; R_0805_2012Metric_Pad1.20x1.40mm_HandSolder
R2: 2.2K; R_0805_2012Metric_Pad1.20x1.40mm_HandSolder
R6, R8: 10K; R_0805_2012Metric_Pad1.20x1.40mm_HandSolder
R7: 22K; R_0805_2012Metric_Pad1.20x1.40mm_HandSolder
TH1, TH2: Thermistor; R_2010_5025Metric_Pad1.40x2.65mm_HandSolder
TH201: 500mA Thermistor; R_2010_5025Metric_Pad1.40x2.65mm_HandSolder
U2: esp32-c3-ebay; ESP-C3-Zero-ebay
U3: LP2985-3.3; SOT-23-5
U4: PC817; DIP-4_W7.62mm
U5: DCDCConverter; Mini360 DCDCConverter
U7: STIS0621; SOIC-8_3.9x4.9mm_P1.27mm
U102: TJA1050; SOIC-8_3.9x4.9mm_P1.27mm

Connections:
3.3V BMS: C5.1, U3.5 (VOUT), U7.8 (VDD2)
3v3: U2.14 (3v3), U7.1 (VDD1)
5.8V: C206.1, D105.1 (A), U5.3 (Outv)
5V: C1.2, C105.2, D105.2 (K), R8.2, U2.16 (5v), U102.3 (Vcc)
12V BMS: C7.1, P102.4, R7.2, U3.1 (VIN)
12v: P101.1, TH201.2
12vFused: C205.1, D203.2 (K), D204.2 (K), TH201.1, U5.1 (12v)
BMS-RX: U2.13 (gpio4), U7.2 (VOA)
BMS-TX: U2.11 (gpio2), U7.3 (VIB)
CAN-H: P101.4, TH1.1
CAN-L: P101.3, TH2.1
CAN-RX: R1.2, R2.2, U2.4 (gpio8)
CAN-TX: U2.6 (gpio10), U102.1 (TXD)
GND: C1.1, C105.1, C205.2, C206.2, D101.1 (A), D102.1 (A), D203.1 (A), D204.1 (A), P101.2, R1.1, U2.15 (gnd), U4.2, U5.2 (Gnd), U5.4 (Gnd), U7.4 (GND1), U102.2 (GND), U102.8 (S)
GND BMS: C5.2, C6.2, C7.2, P102.1, R6.2, U3.2 (GND), U7.5 (GND2)
unnamed: D101.2 (K), TH2.2, U102.6 (CanL)
unnamed: D102.2 (K), TH1.2, U102.7 (CanH)
unnamed: R7.1, U4.4
unnamed: R8.1, U4.1
unnamed: C6.1, U3.4 (BP)
unnamed: R6.1, U3.3 (ON/~OFF), U4.3
unnamed: R2.1, U102.4 (RXD)
RX from BMS: P102.3, U7.7 (VIA)
TX to BMS: P102.2, U7.6 (VOB)

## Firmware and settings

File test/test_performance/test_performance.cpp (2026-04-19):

// Native macOS harness for lib/performance.
//
// Two modes:
//
//   generate [seed [n [out]]]   -> write a CSV of random inputs + derived
//                                  values. Used to (re)build the checked-in
//                                  reference_output.csv after an intentional
//                                  algorithm change.
//
//   verify <ref.csv>            -> regression test. Reads the reference file,
//                                  re-runs Performance::update for each row's
//                                  inputs, and compares the recomputed derived
//                                  values against the stored ones.
//
// Inputs are the fields emitted by the NMEABridge Nav Service (see
// docs/ble-transport.md): awa, aws, stw, heading (hdm), variation. Roll is
// not emitted by the nav service, so it is pinned at the "not available"
// sentinel (-1e9).
//
// `make test` runs verify against reference_output.csv.
// `make generate` rebuilds the reference.

// STL first so the Arduino-style `abs` macro in the shims does not pollute
// standard headers parsed later in the translation unit.
#include <cmath>
#include <cstdint>
#include <cstdio>
#include <cstdlib>
#include <cstring>
#include <random>
#include <string>
#include <vector>

#include "performance.h"

static unsigned long g_millis = 0;
extern "C" unsigned long millis(void) { return g_millis; }

class FilePrint : public Print {
public:
    explicit FilePrint(FILE *f) : out(f) {}
    void print(const char *s) override { std::fprintf(out, "%s", s); }
    void print(float f) override { std::fprintf(out, "%.6f", f); }
    void println(const char *s) override { std::fprintf(out, "%s\n", s); }
private:
    FILE *out;
};

class BufferPrint : public Print {
public:
    std::string buf;
    void print(const char *s) override { buf += s; }
    void print(float f) override {
        char tmp[32];
        std::snprintf(tmp, sizeof(tmp), "%.6f", f);
        buf += tmp;
    }
    void println(const char *s) override { buf += s; buf += '\n'; }
};

static const int NUM_DERIVED = 17;
static const char *CSV_HEADER =
    "iter,awa,aws,stw,roll,hdm,variation,"
    "tag,tws,twa,leeway,polarSpeed,polarSpeedRatio,polarVmg,vmg,"
    "targetTwa,targetVmg,targetStw,polarVmgRatio,"
    "windDirectionTrue,windDirectionMagnetic,"
    "oppositeTrackHeadingTrue,oppositeTrackHeadingMagnetic,"
    "oppositeTrackTrue,oppositeTrackMagnetic";

static const char *DERIVED_NAMES[NUM_DERIVED] = {
    "tws", "twa", "leeway", "polarSpeed", "polarSpeedRatio", "polarVmg", "vmg",
    "targetTwa", "targetVmg", "targetStw", "polarVmgRatio",
    "windDirectionTrue", "windDirectionMagnetic",
    "oppositeTrackHeadingTrue", "oppositeTrackHeadingMagnetic",
    "oppositeTrackTrue", "oppositeTrackMagnetic"
};

static void splitCsv(const std::string &line, std::vector<std::string> &out) {
    out.clear();
    std::string cur;
    for (char c : line) {
        if (c == ',') { out.push_back(cur); cur.clear(); }
        else cur.push_back(c);
    }
    out.push_back(cur);
}

// Invert the forward equations in Performance::update to turn a desired
// (tws, twa, stw) into the (awa, aws) that would produce it. Used by the
// grid sweep so we can target specific polar cells.
//
// Forward (from performance.cpp):
//   apparentX = cos(awa) * aws
//   apparentY = sin(awa) * aws
//   tws = sqrt(apparentY^2 + (apparentX - stw)^2)
//   twa = atan2(apparentY, apparentX - stw)
// Inverse:
//   apparent_vec = true_vec + (stw, 0)
//   aws = |apparent_vec|;  awa = atan2(apparent_vec.y, apparent_vec.x)
static void invertToApparent(float tws_ms, float twa, float stw,
                             float &awa, float &aws) {
    float trueX = tws_ms * std::cos(twa);
    float trueY = tws_ms * std::sin(twa);
    float appX  = trueX + stw;
    float appY  = trueY;
    aws = std::sqrt(appX * appX + appY * appY);
    awa = std::atan2(appY, appX);
}

// Deterministic sweep over the midpoint of every polar cell (TWS 0..30 kn x
// full TWA, both tacks). Ensures every cell of the polar interpolator is
// exercised at least once. Iter counter is advanced in place.
static int emitGrid(FILE *out, Performance &perf, FilePrint &printer, int iter) {
    // Midpoints of the polar_tws cells up to 30 kn.
    // Polar breakpoints: 0, 4, 6, 8, 10, 12, 14, 16, 20, 25, 30 (kn)
    const float tws_mids_kn[] = {
        2.f, 5.f, 7.f, 9.f, 11.f, 13.f, 15.f, 18.f, 22.5f, 27.5f
    };
    // Midpoints of the polar_twa cells.
    // Polar breakpoints: 0, 5, 10, 15, 20, 25, 32, 36, 40, 45, 52, 60, 70, 80,
    //                    90, 100, 110, 120, 130, 140, 150, 160, 170, 180 (deg)
    const float twa_mids_deg[] = {
        2.5f, 7.5f, 12.5f, 17.5f, 22.5f, 28.5f, 34.f, 38.f, 42.5f, 48.5f,
        56.f, 65.f, 75.f, 85.f, 95.f, 105.f, 115.f, 125.f, 135.f, 145.f,
        155.f, 165.f, 175.f
    };
    const int n_tws = (int)(sizeof(tws_mids_kn) / sizeof(tws_mids_kn[0]));
    const int n_twa = (int)(sizeof(twa_mids_deg) / sizeof(twa_mids_deg[0]));

    const float MS_PER_KN = 0.514444257f;
    const float DEG_TO_RAD = (float)(M_PI / 180.0);
    const float ROLL_NA = -1e9f;

    // Fixed boat speed + orientation for the grid. stw chosen so apparent
    // wind stays well-defined for every cell; hdm and variation are arbitrary
    // but fixed so the wind-direction / opposite-track outputs are reproducible.
    const float stw = 2.5f;   // m/s (~4.9 kn)
    const float hdm = 1.0f;   // rad
    const float var = 0.1f;   // rad

    for (int ti = 0; ti < n_tws; ti++) {
        float tws_ms = tws_mids_kn[ti] * MS_PER_KN;
        for (int ai = 0; ai < n_twa; ai++) {
            for (int sign = 1; sign >= -1; sign -= 2) {
                float twa = (float)sign * twa_mids_deg[ai] * DEG_TO_RAD;
                float awa, aws;
                invertToApparent(tws_ms, twa, stw, awa, aws);

                g_millis += 1000;
                std::fprintf(out, "%d,%.9f,%.9f,%.9f,%.1f,%.9f,%.9f,",
                             iter, awa, aws, stw, ROLL_NA, hdm, var);
                perf.update(awa, aws, stw, ROLL_NA, hdm, var);
                perf.output(&printer);
                iter++;
            }
        }
    }
    return iter;
}

static int generate(unsigned seed, int n_random, const char *out_path) {
    FILE *out = stdout;
    if (out_path) {
        out = std::fopen(out_path, "w");
        if (!out) {
            std::fprintf(stderr, "cannot open %s for writing\n", out_path);
            return 1;
        }
    }

    // Grid rows are deterministic; random rows use the seed. Keep both numbers
    // in the header comment so the file is self-describing.
    // Grid dimensions: 10 TWS * 23 TWA * 2 tacks = 460 rows.
    const int n_grid = 10 * 23 * 2;
    std::fprintf(out, "# seed=%u grid_rows=%d random_rows=%d\n",
                 seed, n_grid, n_random);
    std::fprintf(out, "%s\n", CSV_HEADER);

    NMEA0183N2KMessages encoder;
    Performance perf(&encoder);
    FilePrint printer(out);
    g_millis = 0;

    int iter = 0;
    iter = emitGrid(out, perf, printer, iter);

    std::mt19937 rng(seed);
    // Input ranges from docs/ble-transport.md NMEABridge Nav Service (0xFF01).
    // Wind / water speed ranges are clipped to physically meaningful marine
    // values (the BLE field supports up to 655.34 m/s but that is never
    // realistic). Adjust if you want to exercise extreme encoder edges.
    const float PI_F = (float)M_PI;
    std::uniform_real_distribution<float> awaDist(0.0f, 2.0f * PI_F);
    std::uniform_real_distribution<float> awsDist(0.0f, 25.0f);
    std::uniform_real_distribution<float> stwDist(0.0f, 12.0f);
    std::uniform_real_distribution<float> hdmDist(0.0f, 2.0f * PI_F);
    std::uniform_real_distribution<float> varDist(-PI_F, PI_F);

    const float ROLL_NA = -1e9f;

    for (int i = 0; i < n_random; i++) {
        g_millis += 1000;  // step past MIN_CALCULATION_PERIOD (500 ms)
        float awa = awaDist(rng);
        float aws = awsDist(rng);
        float stw = stwDist(rng);
        float hdm = hdmDist(rng);
        float var = varDist(rng);

        std::fprintf(out, "%d,%.9f,%.9f,%.9f,%.1f,%.9f,%.9f,",
                     iter, awa, aws, stw, ROLL_NA, hdm, var);

        perf.update(awa, aws, stw, ROLL_NA, hdm, var);
        // output() writes: "P,<17 derived fields separated by commas>,\n".
        // Sentinel values (-1e9) are rendered as empty fields.
        perf.output(&printer);
        iter++;
    }

    if (out_path) std::fclose(out);
    return 0;
}

// Returns true if the two float fields match. Empty string represents the
// -1e9 "not available" sentinel; empty must match empty exactly.
static bool fieldsMatch(const std::string &expected, const std::string &got,
                        float absTol, float relTol,
                        float &expVal, float &gotVal, bool &expSentinel, bool &gotSentinel) {
    expSentinel = expected.empty();
    gotSentinel = got.empty();
    expVal = 0.0f; gotVal = 0.0f;
    if (expSentinel || gotSentinel) return expSentinel == gotSentinel;

    expVal = std::strtof(expected.c_str(), nullptr);
    gotVal = std::strtof(got.c_str(), nullptr);
    if (expVal == gotVal) return true;
    float diff = std::fabs(expVal - gotVal);
    if (diff <= absTol) return true;
    float mag = std::fmax(std::fabs(expVal), std::fabs(gotVal));
    return diff <= relTol * mag;
}

static int verify(const char *path) {
    FILE *f = std::fopen(path, "r");
    if (!f) { std::fprintf(stderr, "cannot open %s\n", path); return 2; }

    NMEA0183N2KMessages encoder;
    Performance perf(&encoder);

    // Tolerance chosen well above CSV round-trip rounding (6 decimals, ~5e-7)
    // and well below magnitudes that would indicate a real algorithm change.
    const float ABS_TOL = 1e-5f;
    const float REL_TOL = 1e-5f;

    char raw[4096];
    int rowsChecked = 0;
    int rowMismatches = 0;
    int fieldMismatches = 0;
    const int MAX_REPORT = 20;
    int reported = 0;

    g_millis = 0;
    while (std::fgets(raw, sizeof(raw), f)) {
        size_t len = std::strlen(raw);
        while (len > 0 && (raw[len-1] == '\n' || raw[len-1] == '\r')) raw[--len] = '\0';
        if (len == 0) continue;
        if (raw[0] == '#') continue;
        // header row starts with "iter"
        if (raw[0] == 'i') continue;

        std::string line(raw);
        std::vector<std::string> toks;
        splitCsv(line, toks);

        // Expected layout: 7 input fields, "P" tag, 17 derived fields, and
        // output() emits a trailing comma -> one empty token at the end.
        if ((int)toks.size() < 7 + 1 + NUM_DERIVED) {
            std::fprintf(stderr, "row %d: malformed (%zu fields)\n", rowsChecked, toks.size());
            return 2;
        }

        int iter = std::atoi(toks[0].c_str());
        float awa  = std::strtof(toks[1].c_str(), nullptr);
        float aws  = std::strtof(toks[2].c_str(), nullptr);
        float stw  = std::strtof(toks[3].c_str(), nullptr);
        float roll = std::strtof(toks[4].c_str(), nullptr);
        float hdm  = std::strtof(toks[5].c_str(), nullptr);
        float var  = std::strtof(toks[6].c_str(), nullptr);
        // toks[7] should be "P"

        g_millis += 1000;
        perf.update(awa, aws, stw, roll, hdm, var);

        BufferPrint bp;
        perf.output(&bp);
        // bp.buf -> "P,v1,v2,...,v17,\n"
        std::string got = bp.buf;
        if (!got.empty() && got.back() == '\n') got.pop_back();
        std::vector<std::string> gotToks;
        splitCsv(got, gotToks);

        bool rowHasMismatch = false;
        for (int j = 0; j < NUM_DERIVED; j++) {
            const std::string &exp = toks[8 + j];
            const std::string &g   = (int)gotToks.size() > 1 + j ? gotToks[1 + j] : std::string();
            float ev, gv;
            bool eS, gS;
            if (!fieldsMatch(exp, g, ABS_TOL, REL_TOL, ev, gv, eS, gS)) {
                fieldMismatches++;
                rowHasMismatch = true;
                if (reported < MAX_REPORT) {
                    std::fprintf(stderr,
                        "row iter=%d field=%s expected=%s got=%s (diff=%g)\n",
                        iter, DERIVED_NAMES[j],
                        eS ? "<NA>" : exp.c_str(),
                        gS ? "<NA>" : g.c_str(),
                        (eS || gS) ? 0.0 : (double)std::fabs(ev - gv));
                    reported++;
                }
            }
        }
        if (rowHasMismatch) rowMismatches++;
        rowsChecked++;
    }
    std::fclose(f);

    std::fprintf(stderr,
        "checked %d rows; %d rows with mismatches; %d field mismatches total\n",
        rowsChecked, rowMismatches, fieldMismatches);
    if (reported == MAX_REPORT && fieldMismatches > MAX_REPORT) {
        std::fprintf(stderr, "(further mismatches suppressed)\n");
    }
    return fieldMismatches == 0 ? 0 : 1;
}

static int usage() {
    std::fprintf(stderr,
        "usage:\n"
        "  test_performance generate [seed [n [out.csv]]]\n"
        "  test_performance verify <ref.csv>\n");
    return 2;
}

int main(int argc, char **argv) {
    if (argc < 2) return usage();
    std::string mode = argv[1];
    if (mode == "generate") {
        unsigned seed = 42;
        int n = 1000;
        const char *out = nullptr;
        if (argc > 2) seed = (unsigned)std::strtoul(argv[2], nullptr, 10);
        if (argc > 3) n = std::atoi(argv[3]);
        if (argc > 4) out = argv[4];
        return generate(seed, n, out);
    }
    if (mode == "verify") {
        if (argc < 3) return usage();
        return verify(argv[2]);
    }
    return usage();
}

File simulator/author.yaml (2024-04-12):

apiVersion: v1
kind: Pod
metadata:
  annotations:
    Adobe.ArchPath: MC.Experience Manager.Cloud
    Adobe.CostCenter: ""
    Adobe.Environment: dev
    Adobe.Owner: ""
    Adobe.SKMSServiceId: "3890"
    aemBaseVersion: "6.5"
    aemEnvId: "0"
    aemEnvName: dev42
    aemEnvType: dev
    aemFarm: author
    aemImsOrgId: ""
    aemIsPreviewTier: "false"
    aemIsSecondaryPublishTier: "false"
    aemProgram: AEM-K8s-Base
    aemProgramId: "1"
    aemProgramType: standard
    aemReleaseId: ""
    aemSandbox: "false"
    aemService: test-100
    aemTenantId: aemk8s-helm-dev
    aemTier: author
    arc.ethos.adobe.net/notice.cpu: Pod resource requests changed by ns-team-assets-aws
      target policy
    arc.ethos.adobe.net/notice.memory: Pod resource requests changed by ns-team-assets-aws
      target policy
    arc.ethos.adobe.net/original.cpu.fluent-bit: 30m
    arc.ethos.adobe.net/original.cpu.service-warmup: 70m
    arc.ethos.adobe.net/original.cpu.sidecar-monitor: 16m
    arc.ethos.adobe.net/original.cpu.test-100-aem-author: "1"
    arc.ethos.adobe.net/original.memory.service-warmup: 70Mi
    arc.ethos.adobe.net/original.memory.sidecar-monitor: 200Mi
    arc.ethos.adobe.net/original.memory.test-100-aem-author: 6Gi
    checksum/config-configmap: 5d698f7d180461150155464074282a26270782c4674e4fde9d7b4224358af716
    checksum/customer-secrets: 01ba4719c80b6fe911b091a7c05124b64eeece964e09c058ef8f9805daca546b
    checksum/customer-variables: 01ba4719c80b6fe911b091a7c05124b64eeece964e09c058ef8f9805daca546b
    gatekeeper.sh/mutation-id: 2d9383f8-131b-4557-8bf4-09ea788a7a7c
    gatekeeper.sh/mutations: Assign//psp-default-allowprivilegeescalation-init:1,
      Assign//psp-default-allowprivilegeescalation:1, Assign//psp-readonlyrootfs-init:1,
      Assign//psp-readonlyrootfs:1, Assign//psp-users-fsgroup:1, Assign//psp-users-supplementalgroups:1,
      AssignMetadata//psp-seccomp:1, ModifySet//psp-capabilities-add-init:3, ModifySet//psp-capabilities-add:3,
      ModifySet//psp-capabilities-drop-init:3, ModifySet//psp-capabilities-drop:3
    prometheus.io/port: "8080"
    prometheus.io/scrape: "true"
    seccomp.security.alpha.kubernetes.io/pod: runtime/default
  creationTimestamp: "2024-04-05T20:48:27Z"
  generateName: test-100-aem-author-5c86ff94cd-
  labels:
    app: test-100-aem-author
    appType: author
    hpaoption_container_cpu_named: test-100-aem-author
    netpol-egress-content-distribution: "true"
    netpol-egress-egress-proxy: "false"
    netpol-egress-eventing-proxy: "true"
    netpol-egress-external-http: "true"
    netpol-egress-external-https: "true"
    netpol-egress-external-mongo: "true"
    netpol-egress-formsdocservice: "true"
    netpol-egress-invalidation-service: "true"
    netpol-egress-logstash: "true"
    netpol-egress-loki-proxy-3100: "true"
    netpol-egress-pipeline-proxy: "true"
    netpol-egress-prometheus-push-gw: "true"
    netpol-egress-redis: "true"
    netpol-egress-release-toggles-svc: "true"
    netpol-ingress-content-backflow-job-8080: "true"
    netpol-ingress-index-updates-job-8080: "true"
    netpol-ingress-indexing-job-author-8080: "true"
    netpol-ingress-maem-author-job-8080: "true"
    netpol-ingress-maintenance-job-8080: "true"
    netpol-ingress-prometheus-server: "true"
    netpol-ingress-skyline-fcdc-8080: "true"
    netpol-ingress-web-8080: "true"
    pod-template-hash: 5c86ff94cd
    release: test-100
  name: test-100-aem-author-5c86ff94cd-vbww9
  namespace: ns-team-assets-aws
  ownerReferences:
  - apiVersion: apps/v1
    blockOwnerDeletion: true
    controller: true
    kind: ReplicaSet
    name: test-100-aem-author-5c86ff94cd
    uid: 75eb3cc4-5f99-4a85-840a-f0e78f15f61a
  resourceVersion: "2218849772"
  uid: 79b9048c-cb1d-4015-92f4-877d825e1912
spec:
  containers:
  - env:
    - name: AEM_IS_CLOUDSDK_TIER
    - name: AEM_CLOUDSDK_RESET_COUNTER
      value: "0000"
    - name: assetComputeEndpoint
      valueFrom:
        configMapKeyRef:
          key: assetComputeEndpoint
          name: test-100-aem-config
    - name: assetComputeScanEnabled
      valueFrom:
        configMapKeyRef:
          key: assetComputeScanEnabled
          name: test-100-aem-config
    - name: assetComputeBulkImportDisabled
      valueFrom:
        configMapKeyRef:
          key: assetComputeBulkImportDisabled
          name: test-100-aem-config
    - name: customerIntegrationsClientId
      value: test-100-integration
    - name: nodestore
      value: global-mongo
    - name: blobstore
      value: aws
    - name: slingJobProgressLogMaxCount
      value: "-1"
    - name: authorPersistentCacheConfig
      value: '-'
    - name: throttlingEnabled
      value: "false"
    - name: suspendTimeoutMillis
      value: "60000"
    - name: ETHOS_CONTAINER_ID
      value: author
    - name: ETHOS_ENV_NAME
      value: dev01
    - name: MALLOC_ARENA_MAX
      value: "1"
    - name: BBC_JAVA_MAX_MEM_RATIO
      value: "75"
    - name: javaargs
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

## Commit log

2024-04-06 Removed old pcb files
    [BatteryMonitor.kicad_pcb, BatteryMonitor.sch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]
2024-04-08 Added pgn output on websockets with filtering
2024-04-29 Added an admin interface for the device filesystem
2024-05-02 Added a frame filter for ws endpoints, and improved packet handling and recovery
2024-06-22 More inteactivity on LifePo4 BMS graphs
2024-06-23 Added charge dischage guage
2024-10-28 Dropped websocket use as the ESPAsyncWebServer implementaton crashes frequently, switched to use chunked streaming over http
2024-11-11 Intgrated BMS into module and redesigned boards
    [ESP32CanBoard-2024-11-06-19-33-43.sch, ESP32CanBoard.kicad_pcb, ESP32CanBoard.kicad_sch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]
2024-11-12 Updated boards and readme
    [esp32-c3-board-waveshare.kicad_pcb, esp32-c3-board.kicad_pcb]
2024-11-16 Working version on esp32C3 firmware
    [esp32-c3-board.kicad_pcb, esp32-c3-board.kicad_sch]
2024-11-18 messed up bms uart connector
    [esp32-c3-board.kicad_pcb, esp32-c3-board.kicad_sch]
2024-12-17 Added some doc and images
    [case.scad, case.stl, lid.stl]
2024-12-20 Fixed BMS UI against real firmware
2024-12-21 Tested and fixed E2E with bms simulator
2024-12-21 Fixed missing bms graphs
2024-12-21 Fixed main ui to use better startup from the bms app
2024-12-22 Fixed some sensors and admin login failure
2024-12-22 Added simpler default UI in the FW
    [example-config.txt]
2024-12-22 Fixed soc and capacity graphs
2024-12-22 Fixed dump status message for bms
2024-12-23 Added better device UI, still needs more work
2024-12-24 Split UIs into their own repos
    [example-config.txt]
2025-01-18 Working version connected to real BMS
    [esp32-c3-board.kicad_pcb, esp32-c3-board.kicad_sch]
2025-01-19 Included simulations
    [case.scad, case.stl, esp32-c3-board.kicad_pcb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]
2025-02-05 Added standard DNS server to improve lookups
    [case.scad]
2025-02-08 Fixed message boundary corruption in bms
2025-06-23 Added faster update for BMS messages and send seasmart via POST
2025-06-27 Added transport for inbound seasmart messages with a pgn filter
2025-07-08 Added engine Freeze frame functoinality
    [esp32-c3-board.kicad_pcb, esp32-c3-board.kicad_sch]
2025-07-16 Updated simulator to handle freeze frames
2025-08-19 Improve stability and reduce network load from 20KB/s per connecton to 2KB/s, ESP32-C3 cant handle much
2026-04-04 Fixed some bugs and made it possible to start and stop the network with the device powered from the BMS rather than can bus
    [esp32-c3-board-bms.kicad_pcb, esp32-c3-board-bms.kicad_sch]
2026-04-05 Board redesigned to be isolated from the can rather than bms
    [esp32-c3-board-bms.kicad_pcb, esp32-c3-board-bms.kicad_sch]
2026-04-07 updated board, ready for fab
    [esp32-c3-board-bms.kicad_pcb, esp32-c3-board-bms.kicad_sch]
2026-04-18 New case and fixed bootloop
    [case.scad, case.stl, lid.stl]
2026-04-19 Added test method for derived values
    [reference_output.csv]
2026-04-19 Fixed strid 18 bug in polar. Thats bug might be everywhere, need to check
    [reference_output.csv]
2026-04-20 updated gitignore for kicad tmp files
2026-04-21 Reporting on BMS status
2026-04-22 Added ability to bring Can up without voltage for testing
2026-04-22 Revert "Added ability to bring Can up without voltage for testing"
    This reverts commit 78cff7f1a8ab07a4fa78700b39b697a673bc1f74.
2026-04-22 Revert "Added ability to bring Can up without voltage for testing"
    This reverts commit f13b89df9145439b69aa177063b1d98d4b0a8c6c.
2026-04-30 Fixed missing temperature fields
2026-05-04 onboard MP2307 DCDC
    [esp32-c3-board-bms.kicad_pcb, esp32-c3-board-bms.kicad_sch]
2026-05-14 Added IDF build incase the ISR is impacted by flash
    [no_ota.csv]
2026-06-16 Integrated FlowMetering
2026-06-17 Moved flowmeter into engine data
2026-06-23 Removing Flowmeter as no longer required
2026-09-01 Adjusted BLE SCA setting to match ESP32-C3 sleep clock accuracy
2026-11-08 Added a 22uF cap to the 3.3v tested a 6C ok
